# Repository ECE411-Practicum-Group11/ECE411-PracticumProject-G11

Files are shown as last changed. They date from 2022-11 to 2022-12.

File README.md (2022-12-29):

Fall 2022 ECE 411 Practicum Project 

<ins>Group 11 Team Members/Project Authors</ins> 
* Cesar Ordaz-Coronel
* Charles Nasser
* Anthony Bruno

# NERD BOX - A Handheld Video Game Console
<p align="center">
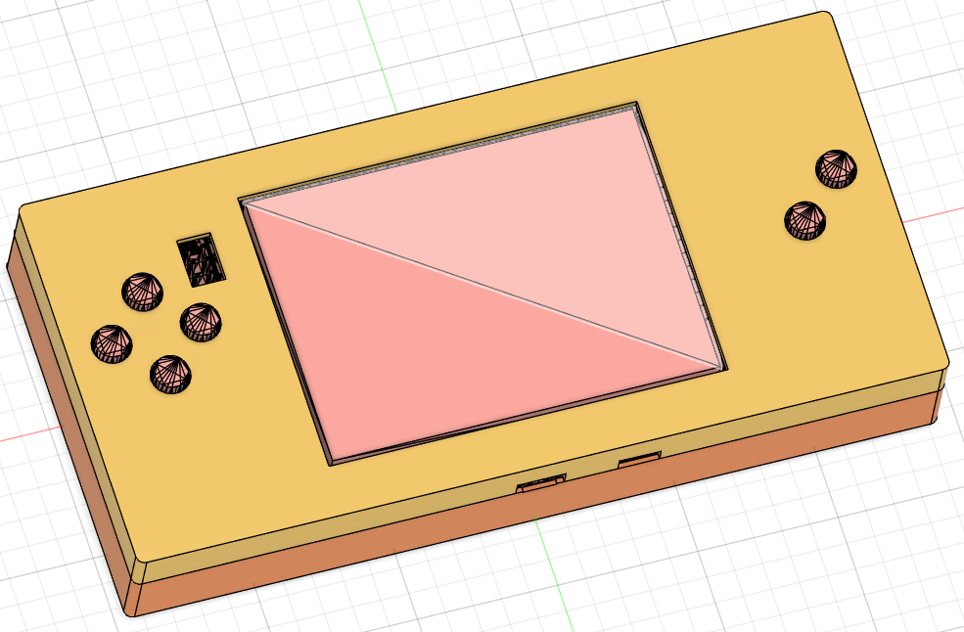
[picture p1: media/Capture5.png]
  
</p>
  
## Description:
This practicum project is for the development of a **Handheld Video Game Console**. This gaming device has buttons for users to interact with the device electronics and view game graphics/animations on the console's display. This device was designed for beginner-electronics users who want to code their own games (also build/modify/customize their own portable game console). The handheld game console is a portabe device with a simple interface for users.

<p align="center">
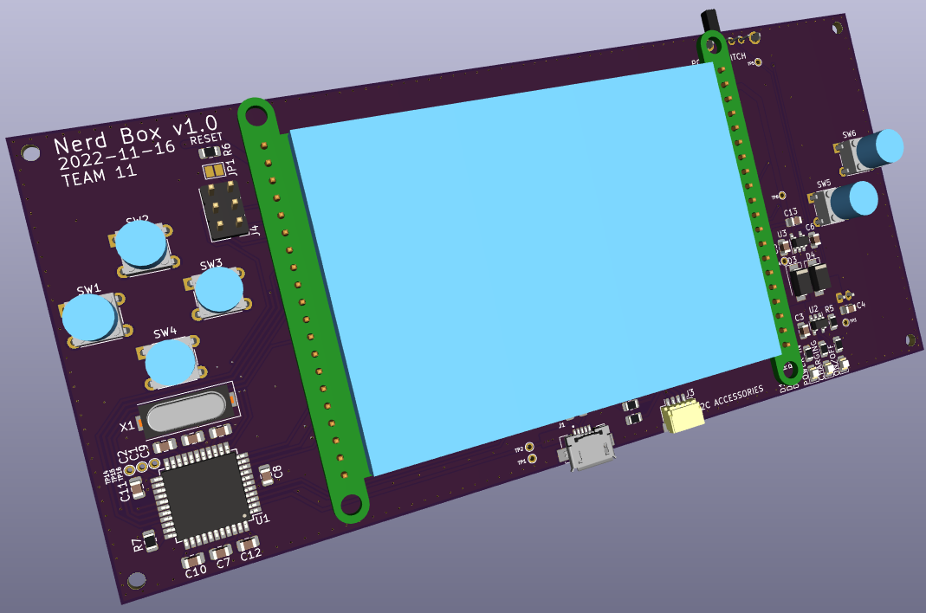
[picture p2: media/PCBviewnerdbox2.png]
  
</p>

This handheld game console was designed with a simple user interface and at a affortable cost. The device contains 4 direction/navigation buttons, 2 action buttons, power switch, and a [QWIIC I2C](https://www.sparkfun.com/qwiic) connector for adding accessory sensors and devices such as an [accelerometer](https://www.sparkfun.com/products/17589) for motion control with the Handheld Video Game Console. The system uses a 3.7V 2000mah LiPo battery that is rechargable through the USB connection. The USB connection serves to not only charge the LiPo battery but also for user to upload their own coded games. This device uses the Arduino IDE (Processing language) to code games and upload/interact with the system electronics hardware. The gaming device has a 3D printed enclosure that can be modified for customized enclosure designs.

## Overview of Repository Folders/Files/Sections

* 411documents - contains all documentation for the this project over the course of 10 weeks. This folder contains Level 1 and Level 0 functional decomposition block diagrams for the device, Bill of Materials, Proposed project schedule (Ghantt Chart), Test plans, project ideas, the Product Design Specification (PDS), device electrical schematics, device PCB layout, and 3D printed CAD files.

* code - This folder contains any code that was generated to run the device, test the device, and debug the device during development. The software in this folder includes test programs, UI code for user, prototype code, and device video game code examples.

* hardware/console-hardware - This folder contains all electrical schematics, PCB layout, components, CAD project, and mechanical CAD files. This is the main folder for DIY building, fabrication, modifications, or reworking this prjoect.

* media - this folder contains all media related to this project. This includes test videos, debugging videos, test images and protoype images, demonstration videos, photos, etc.

* LICENSE file - The current license of this practicum project is CREATIVE COMMONS ZERO V1.0 UNIVERSAL. This is an Open-Source License and this project is dedicated to the public domain. This project can be copied, modified, distributed, and performance of work (including commercial purposes) without asking for permission. For more information on CC0 1.0 Universal - Public Domain Dedication, please follow this link: https://creativecommons.org/publicdomain/zero/1.0/

* README.md file - A markdown file (this file) that explains a majority of the files and folders of this practicum project. 

* Team Information - A markdown file that contains information about the team members of this practicum project.

## System Architecture - Block Diagrams
For more system architecture details, go to the [411documents](https://github.com/ECE411-Practicum-Group11/ECE411-PracticumProject-G11/tree/main/411documents) folder in this repsitory and view the [G11_L1blockDiagram](https://github.com/ECE411-Practicum-Group11/ECE411-PracticumProject-G11/blob/main/411documents/G11_L1_blockDiagram.png)

<p align="center">
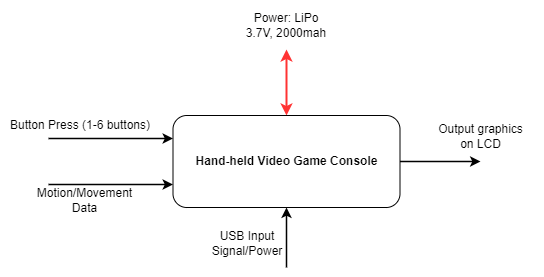
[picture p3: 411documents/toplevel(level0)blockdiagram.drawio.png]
  
</p>

## [Demonstration & Operations Video Link](https://www.youtube.com/playlist?list=PLfQtabAE1AbKebFBLS851gg_HdHH0sS15)

## License
The current license of this practicum project is CREATIVE COMMONS ZERO V1.0 UNIVERSAL. This is an Open-Source License and this project is dedicated to the public domain. This project can be copied, modified, distributed, and performance of work (including commercial purposes) without asking for permission. For more information on CC0 1.0 Universal - Public Domain Dedication, please follow this link: https://creativecommons.org/publicdomain/zero/1.0/

## How to Download Project & Tools to Use
1) Go to the project [Repository](https://github.com/ECE411-Practicum-Group11/ECE411-PracticumProject-G11)

2) Use one of the following options

### Option 1: Download ZIP
1) Click the GREEN "<>Code" dropdown.

2) Click on "Download ZIP".

3) After the download is complete, unzip the folder using [7zip](https://www.7-zip.org/), [PeaZip](https://peazip.github.io/), [WinZip](https://www.winzip.com/en/), or any other ZIP application.

### Option 2: Git Clone
If you know how to use Git/GitHub, you can clone the project repository
1) Click the GREEN "<>Code" dropdown.

2) Copy the https git link.

3) Open git bash on your current machine and move to the directly on your local machine where you would like to clone the project repository to.

4) type the following commands.

```
git clone [the http git link you copied, you can use SHIFT + INSERT for this]
```
Now you have a local repository for this project.

You can now access all files and documents of this project

## Tools For this Project
There are a few software tools that you will need in order to build, modify, or view the files in this project.

For the PCB design schematic, PCB layout, and any other items related to the electronics board, you can use any electronics CAD design and automation software. We highly recommend using [KiCAD EDA](https://www.kicad.org/) for this project, a free, open-source electronics CAD EDA.

For the 3D Printed enclosure the project includes STL files and an AutoDesk Fusion 360 Archive file. We recommend you use [Autodesk Fusion360 CAD](https://www.autodesk.com/products/fusion-360/personal) for the 3D printed enclosure, which is free for personal use.

For software development of the device and coding your own games, we recommend you use [Arduino IDE](https://www.arduino.cc/en/software). We also recommend reading the [tutorial for the 2.8" TFT LCD](https://learn.adafruit.com/adafruit-2-8-and-3-2-color-tft-touchscreen-breakout-v2/overview). We also recommend researching some of the libraries used in the original device program for more optimization (i.e [FloppyDerp_with_UI.ino](https://github.com/ECE411-Practicum-Group11/ECE411-PracticumProject-G11/tree/main/code/FloppyDerp_with_UI))

__IMPORTANT NOTE:__ If you plan to use Arduino IDE to upload your own programs and create your own code, you MUST burn the arduino IDE Bootloader to the ATmega32U4 Microcontroller in the project. We HIGHLY recommend you use an Arduino as an ISP for burning the bootloader to the IC. You can follow a tutorial on how to set this up and the burning process at [Arduino as ISP and Arduino Bootloaders](https://docs.arduino.cc/built-in-examples/arduino-isp/ArduinoISP).

__IMPORTANT NOTE:__ If you plan to use Arduino IDE to create code and upload to the Nerd Box, PLEASE set the "Board" under "Tools" dropdown to "Arduino Leonardo"!

## POWERING THE DEVICE!
The Nerd Box has two ways to power the device:
1) Power using LiPo Battery:
The Nerd Box can be powered using a LiPo battery with a JST connector on the back of the PCB. We recommend using a 3.7V, 2000mAh battery. [This one from Adafruit](https://www.adafruit.com/product/2011) is the best since it fits in the chassis and supplies around 40 hours of power to the Nerd Box.

2) Power over USB:
The Nerd Box can also be powered directly over the USB connection. When the Nerd Box's USB is connected, if there is a LiPo battery attached then the LiPo battery will be charged up. THIS IS HOW YOU CHARGE THE LIPO BATTERY IN THE DEVICE. Again the USB serves as a way of charging the LiPo battery and programming/uploading games to the device. The Nerd Box can be powered over the USB without the LiPo battery as well.

## Assembly, Fabrication, Tests Tips & Notes

* We recommend using [Oshpark](https://oshpark.com/) to have your own PCBs fabricated and using [Digi-Key](https://www.digikey.com/) for components.
* If you have a 3D printer or printer service with fine detail/quality, you can modify the 3D enclosure with labels. Otherwise, you can use [decals](https://www.youtube.com/watch?v=YWCaCXiLDwo&t=260s&ab_channel=Tim%27sProjects) on the 3D Prints.
* The recommended screw size and type is a M2.2, self-tapping flat head screw that is roughly 16mm to 19mm in length. Here are some recommendations from McMaster-Carr: [Link 1](https://www.mcmaster.com/catalog/128/3273), [Link 2](https://www.mcmaster.com/catalog/128/3273), [Link 3](https://www.mcmaster.com/screws/tapping-wood-and-drywall-screws/18-8-stainless-steel-phillips-flat-head-screws-for-sheet-metal/screw-size~m2-2/tip-type~pointed/)
* If you are planning to assemble the PCB yourself, we recommend that you solder a subcircuit first and then test with a bench power supply, then test with the LiPo battery. This ensures that everything will operate as expected. The order we recommend from the design schematics are: 3.3V Linear Regulator, LiPo Charger, USB Input Programming & Power, ATmega32U4 + ICSP, the rest of the components. Solder the LCD LAST! Also the board contains different test points. Reference the schematic on what each one does and utilize them in your testing!
* DO NOT USE A HEAT GUN OR PCB OVEN on the PCB with the LCD soldered down to the PCB! THIS WILL DAMAGE IT!
* Consideration: If you plan to have your board fabricated & fitted/assembled by another service, we recommend you add sodler bridges between subcircuits of the device and then add 0Ohm resistors to bridge the subcircuits together. This makes testing each subcircuit easier and able to use an assembly service.
* The 3D Prints for the enclosure don't have any labels for the buttons but you are free to modify the prints with labels. You can also just add decals onto the 3D prints. Go to YouTube or read any tutorials online on how to do this.

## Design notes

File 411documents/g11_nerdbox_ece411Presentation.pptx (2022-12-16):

## Nerd Box

Group 11
Charles Nasser, Cesar Ordaz-Coronel, Anthony Bruno

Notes: Intro slide
Have KiCAD with schematic, board, GitHub with Code section, BOM, Test Results Document,

## Background

The issue addressed:
- Portable Gaming + Open Source Hardware + Game Creation = One Solution
- Values of a Solution: Educational, Creativity, Enjoyment
Today’s Solutions
- High-end solutions = $$$ for individual, Discontinued, moves quickly
- Low-end solutions = Discontinued, sold out, Outdated, other

ArduBoy - Too small form factor

Steam Deck Retail: $400 starting

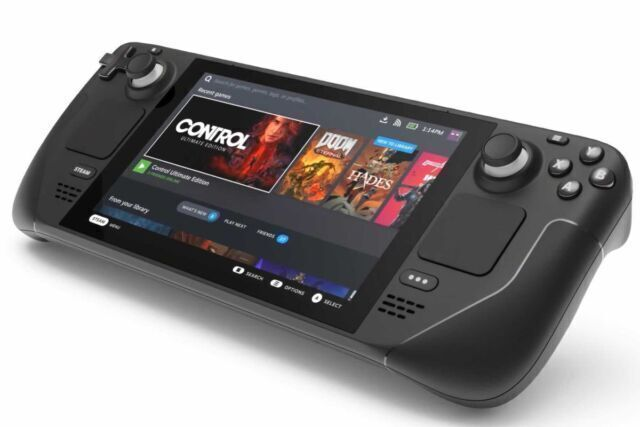
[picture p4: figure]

Meggy Jr RGB - Outdated HW

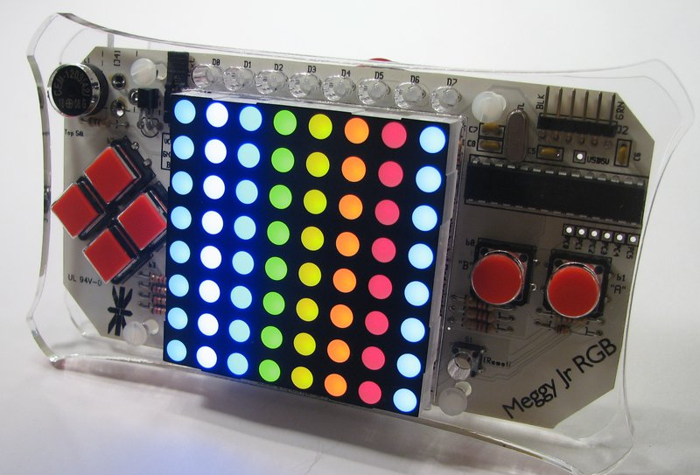
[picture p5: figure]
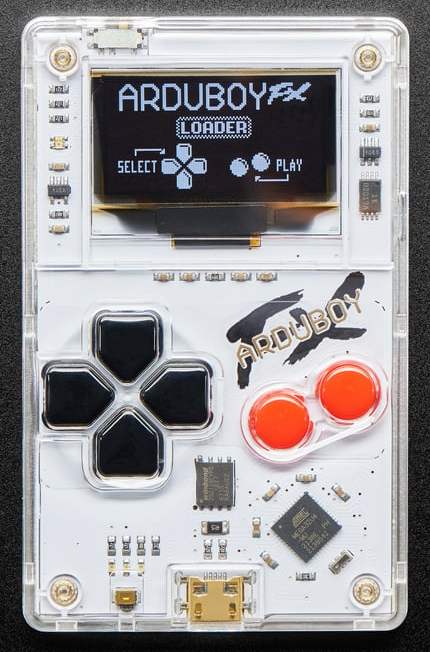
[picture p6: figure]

## Our Approach

Concept of Operations:
- User Input: device buttons, QWIIC (I2C) sensors
- Microcontroller: translates inputs to programmed outputs
- MVP Device Output: Display game animations/graphics
- Device programmed using Arduino IDE or Scratch programming
- USB for charging the battery
Objective: Deliver an open source hardware handheld, programmable gaming console to the video game console market that enables game development/creation and game hardware modification.

## Requirements (Approach continued….)

MUSTS:
- Be Handheld, Portable
- Battery Powered
- User Interface (UI)
- Display Response to inputs
- Menu/Navigation
- Programmable for games

MAYS:
- Memory device for storage of user settings, more memory-heavy games
- Battery Level LED indicators
- Use another monitor to display games on larger displays

SHOULDS:
- Non-button/switch input (motion, CV, etc.)
- 3D Printed Enclosure
- Other non-display outputs (sound, rumble)
- Battery charging

## Design Overview - L0

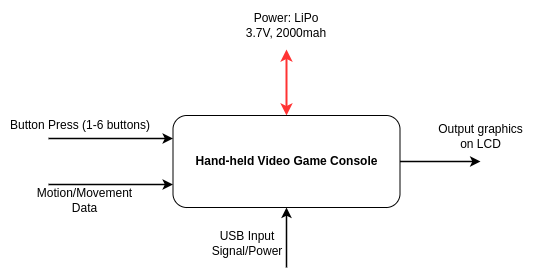
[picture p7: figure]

## Design Overview Continued…. L1

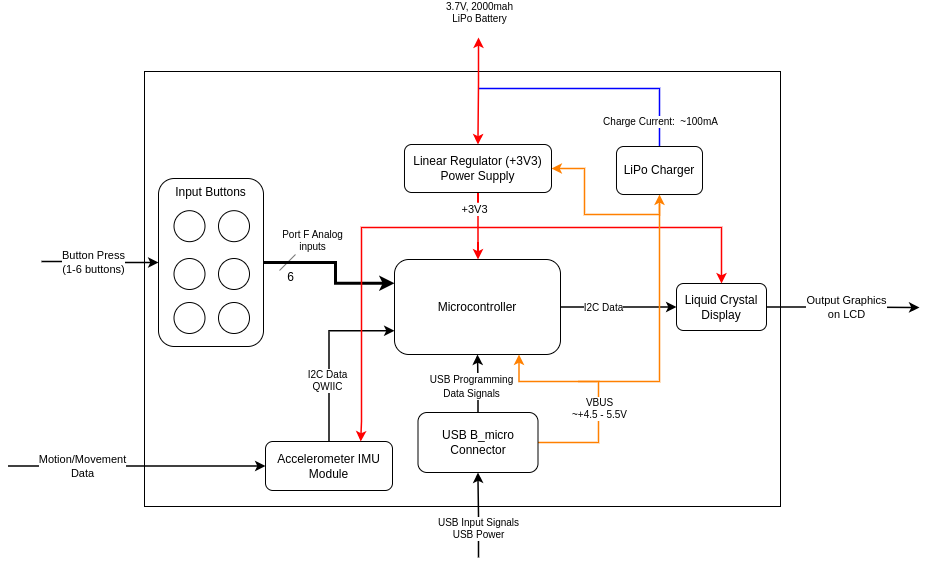
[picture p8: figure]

## Implementation

- Look at Design Schematics (https://github.com/ECE411-Practicum-Group11/ECE411-PracticumProject-G11/blob/main/411documents/console-hardware.pdf)
- Look at Design Board
- Look at Code (https://github.com/ECE411-Practicum-Group11/ECE411-PracticumProject-G11/tree/main/code)
- Tools: Arduino IDE, Fusion 360, kiCAD
- Look at BOM - Bill of Materials (https://docs.google.com/spreadsheets/d/1_oyUwwm-8SEYxP21QnwM3eA1EwvT7GKVv85xH6BpHFg/edit#gid=0)

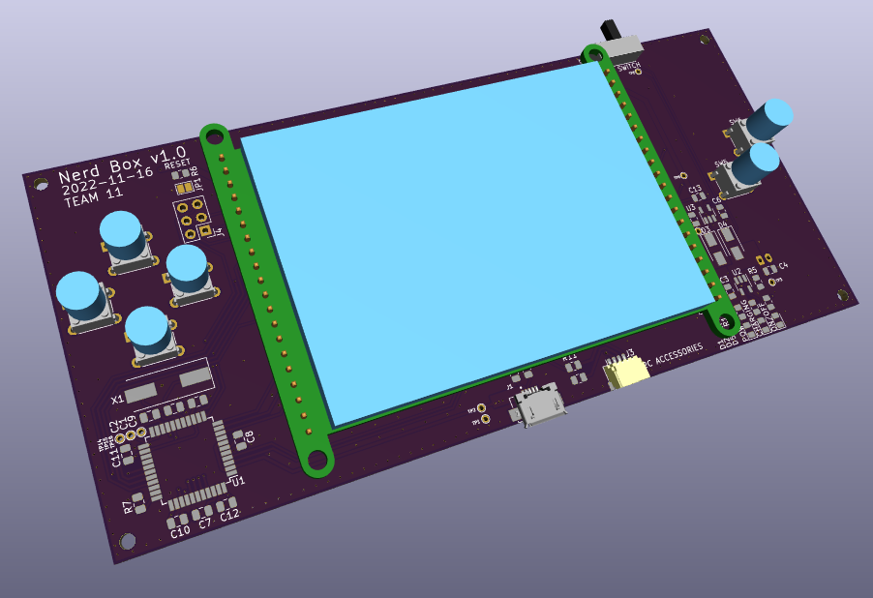
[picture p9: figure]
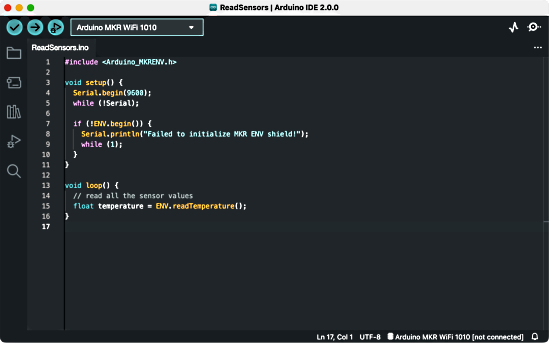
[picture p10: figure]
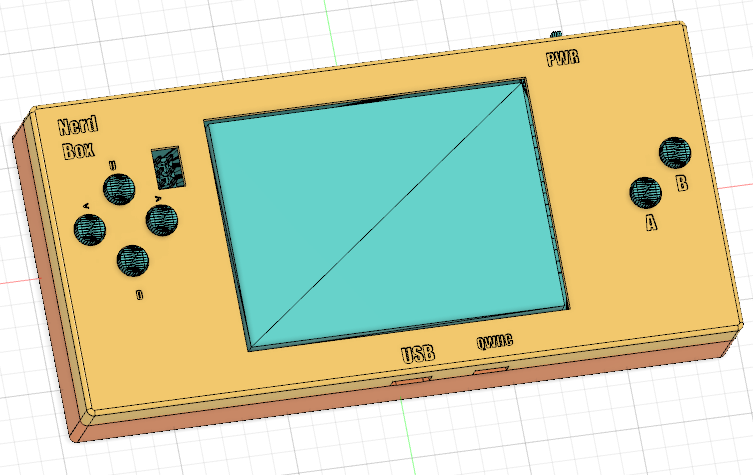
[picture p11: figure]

## IP License & Existing Work

License Chosen: Creative Commons Zero V1.0 Universal (https://creativecommons.org/publicdomain/zero/1.0/)
Other IP used:
- Based on Arduino Leonardo, Lilypad, Andrew Greenberg’s Example schematic (ATmega32U4 µC interface) - For Hardware
- Adafruit library documentation - For code
- Based on example game (https://www.toptal.com/game/ultimate-guide-to-processing-simple-game) coded in processing - Example code reference

## Testing

- In Design/Pre-test setup
  - Placement of Test Points (TP), ~ 16 TP
  - Code simple test software (Serial monitor printing, button presses, etc.)
- Assembly Testing
  - Solder [section] + Run with either Bench supply or Battery + measure TPs OR software testing
  - Section Order:
    - device power supply, LiPo charger, Microcontroller, USB, Display/buttons
  - Take video of tests
- Running the Test Plans → Show in the GDrive (https://drive.google.com/drive/u/0/folders/13O50pw37mKjkBTSg6qUxUUeUvg1ZXIF3)

## Results (for the PROJECT)

What Worked for us
- The output of the regulator showed +3V3
- Device display showing programmed graphics
- Device PASSED written test plans

What didn’t Work well for us
- Bootloader failure → switched to +5V from +3V3
- Display wasn’t functioning properly → Solder/close some pads on the 2.8” TFT display board to use SPI mode
- Problem accessing pins in software → Fixed pin naming in Arduino IDE

## Results (for the TEAM)

What worked for us
- Group communication messaging system (Discord)
- Regular scheduled meetings that fits with our schedules
- Checking each other’s work

What didn’t work so well for us
- Group of 3 (4 is better)
- Working on deliverable assignments day-before due date
- Extra meetings, difficult to schedule

## Contributions

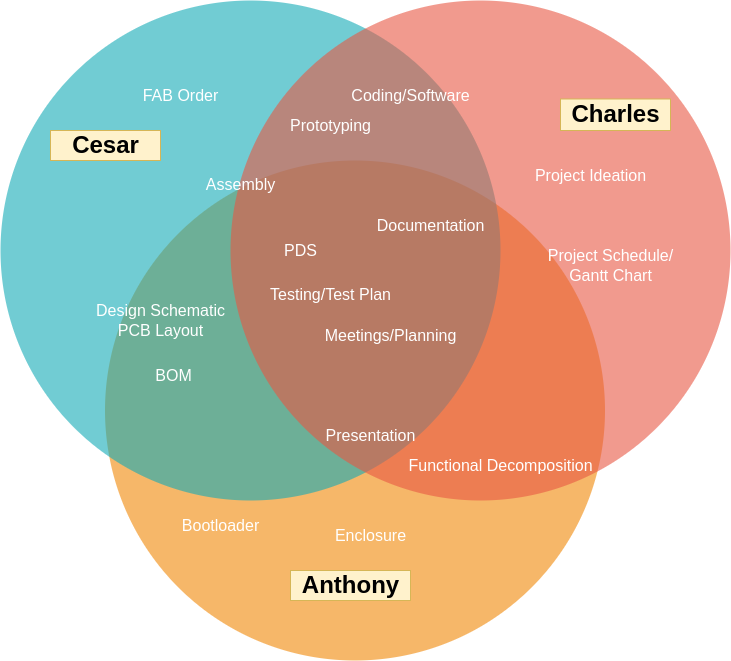
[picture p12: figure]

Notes: Use a venn diagram with each of our names and contributions

## Lessons Learned

- Communication in a project with a short development time is CRITICAL
- Help check each other’s work to verify
- Prototype early, Prototype with better parts
Time Machine - done differently……
- Add more memory w/ a different microcontroller
- Add more output features such as sound
- Add a battery indicator to the LCD
- Easier interface for users to add their code

## Alright….. Let’s Demo Demo Video if necessary

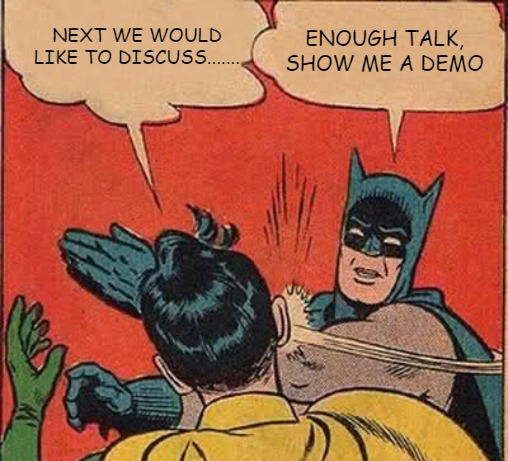
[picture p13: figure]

## Let’s look at the Collaboration site Link Here (https://github.com/ECE411-Practicum-Group11/ECE411-PracticumProject-G11)

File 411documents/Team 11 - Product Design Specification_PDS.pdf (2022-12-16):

# Practicum PDS - Project Design Specifications

Team 11: Anthony Bruno, Charles Nasser, Cesar Ordaz-Coronel

## Executive Summary (Concepts of Operations):

Our device is a handheld video game console. This device displays interactive games where the user interacts with the device (and the game) through a button interface. Users of our device are beginners in electronics who want to code their own games. Users interact with the device through a button system where they can make selections and navigate through the menu. User inputs are output to the display (and possibly a speaker). We have noticed that although there are existing devices, these devices are either discontinued, outdated, sold-out, expensive, or aren’t designed for user-created games. We want the freedom to design our own games that can be run on an open source hardware platform at an affordable cost.

## Brief Market Analysis:

- Intended Customers:
Our device is intended to be an open-source handheld game platform for electronics beginners who want to design/program their own games and play them on a portable device. Ideally, this device allows users to code their own games into it. So our users are those who enjoy open-source hardware and playing/creating handheld games.
- Competition/Differentiation:
The competition in this area is somewhat competitive. There are very high-end systems, such as the Nintendo Switch or Steam Deck, but also low-end systems that are open-source hardware, such as the ArduBoy or Evil Mad Scientist Meggy jr. RGB. However, high-end systems are very expensive to own and don’t offer the ability for users to create their own games (or at least not without a difficult process). Many of the low-end systems today are cheaper but are either sold-out, discontinued, or outdated. Some of them are open-source hardware but creating your own games is not intuitive to the casual observer.
- Estimated Selling Price: ~$65 after mass manufacturing

## Requirements:

Must:
- Be a handheld device that is portable.
- Be battery powered (swappable batteries).
- Have a user interface for the user to interact with the device

- Have the device display respond to a user’s action or input to the device.
- Have a menu for the user to navigate through and make selections.
- Be programmable → The user should be able to upload their own games to the device.

Should:
- Have non-button user input (motion control, computer vision, etc.)
- Have a 3D Printed enclosure to hold the device electronics and act as a handheld form factor for the device.
- Have non-LCD output such as controller rumble or a speaker for sound.
- Have battery charging

May:
- Be used on PC using the Arduino IDE Serial Monitor for display
- Have memory for saving user custom device settings or status of game.
- Have Battery level indicator LEDs.

## System Architecture (L1 Block Diagram):

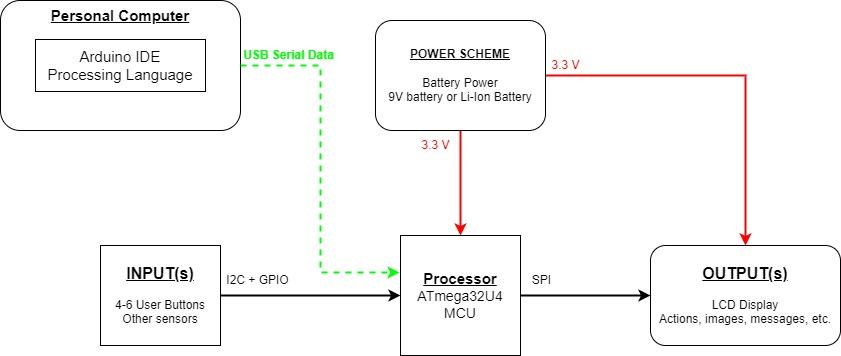
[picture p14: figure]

## Design Specifications:

- Sensor(s)(input): Buttons and motion controls (6-axis IMU)
- Processor: Arduino → ATmega32U4 (Microchip)
- Actuator(output): LCD and haptics (vibration or sound)
- Power Scheme: Battery Powered (9V battery, Li-Ion, LiPo, etc.)
- Mechanical Designs: 3D Printed enclosure
- Firmware/Bootloader:
- Processing (Arduino C++/C)
- Arduino IDE

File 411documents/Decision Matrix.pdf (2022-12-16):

# Practicum Decision Matrix and AHP

Team 11: Anthony, Charles, Cesar

## Question and Criteria

Our group was deciding on which battery technology to use for our handheld video game console. The three options were AA batteries, a 9V battery, and a LiPo battery.
We based this decision on the cost to manufacture, charge capacity, size, whether or not the battery was rechargeable, how easy they are to replace, and the nominal voltage.
We compared manufacture cost by finding rough estimates for the price of each battery when purchased in bulk.
For the charge capacity, we estimated how long the system would last with each battery relative to one another.
We ranked battery size by how much space they would take up, and ranked the thinner LiPo battery higher.
We gave AA batteries and 9V batteries a score of 2 for rechargeability since they are not usually rechargeable, but some can be found, while the LiPo scored 5.
The replacement score was based on how easy and convenient it would be for the user to replace the battery. AA and 9V batteries scored highly, since they are common and cheap, while the LiPo is much more expensive.
The nominal voltage rating was based on how easy it is to power a 3.3V system using the battery technology. AA batteries scored low, since at least 3 of them are needed in series to achieve this, and the 9V battery scored relatively low, since a large voltage drop is needed, which is inefficient when using a linear regulator.

## Decision Matrix

With the decision matrix, we found that the LiPo battery was the best option

AA Batteries (x3) | 9 V | Li-po
Manufacture Cost | 4 | 3 | 4 | 2
Charge Capacity | 4 | 4 | 3 | 4
Size (Small) | 3 | 3 | 3 | 5
Rechargeability | 3 | 2 | 2 | 5
Replacement (Access) | 2 | 5 | 5 | 1
Nominal Voltage | 2 | 2 | 3 | 5
SCORE | | 57 | 59 | 66

## AHP

The AHP method showed that the 9V battery is slightly better than the LiPo battery. This seems to be due to the high importance we gave to manufacturing cost, since the LiPo battery is much more expensive than the alternatives. Despite this, we are still inclined to choose the LiPo battery, which means that cost is less important to us than our weights show.

AHP Analysis | Weights | AA Batteries (x3) | 9V Battery | LiPo Battery
Manufacture Cost | 0.37 | 0.37 | 0.57 | 0.06
Charge Capacity | 0.25 | 0.36 | 0.21 | 0.43
Size (Small) | 0.22 | 0.13 | 0.25 | 0.63
Rechargeability | 0.08 | 0.22 | 0.22 | 0.56
Replacement (Access) | 0.04 | 0.45 | 0.45 | 0.09
Nominal Voltage | 0.04 | 0.20 | 0.30 | 0.50
SCORE | | 0.30 | 0.37 | 0.34

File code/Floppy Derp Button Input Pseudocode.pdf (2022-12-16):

# Pseudocode

Game Selection
1) Floppy Derp
2) Hungover Dude
3) {Insert your game here}

Set game select variable = 1
Button down -> increase var by 1, move cursor over selected game position
- If var = 1, button down does nothing
Button up -> decrease var by 1, move cursor over selected game position
- If var = 3, button up does nothing
“A” Button -> Play selected game (Run game function)

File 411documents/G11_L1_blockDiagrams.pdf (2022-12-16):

# Hand-held Video Game Console: Level 1

Team: G11
Team members: Anthony, Cesar, Charles

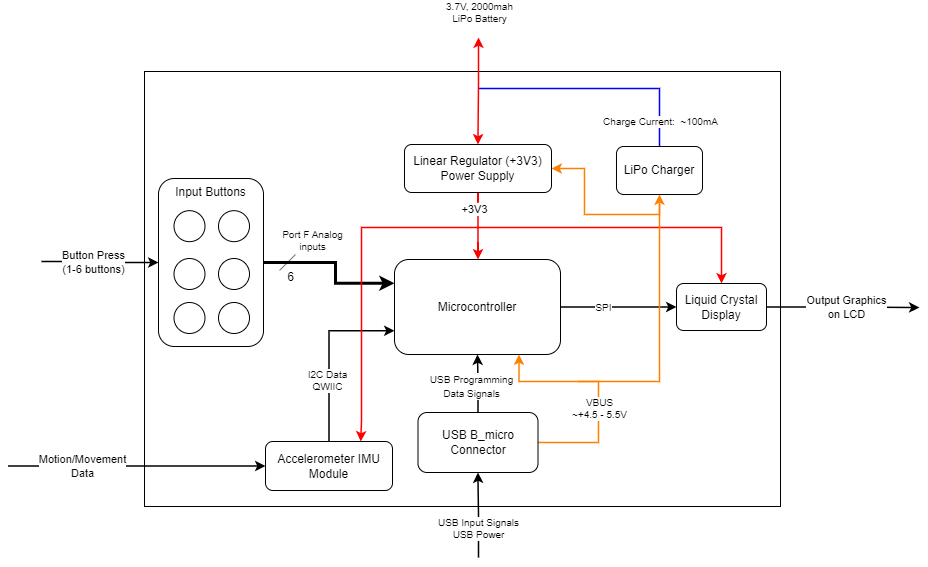
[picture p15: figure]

Microcontroller: Level 1

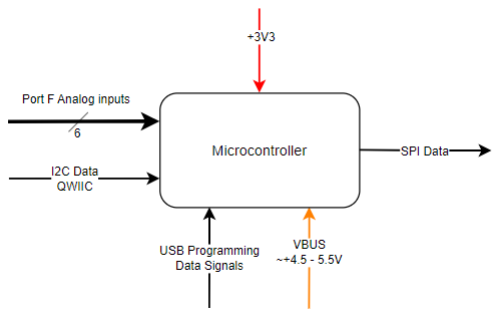
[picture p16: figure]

Module | Microcontroller (ATmega32u4)
Inputs | Port F Analog inputs: 6 analog inputs (pullups) to microcontroller’s ADC I2C Data (QWIIC): 6 DoF IMU data in I2C communication protocol from accelerometer/IMU module. QWIIC is Sparkfun’s I2C interface connection system for prototyping. +3V3: +3.3V DC power for Microcontroller USB Programming Data Signals: USB D+/D- programming signals to program the microcontroller behavior. VBUS (+4.5 - 5.5V): Supply from USB for programming, supplying the microcontroller
Outputs | SPI Data: SPI communication protocol data for graphics and animation on the Liquid Crystal Display module.
Functionality | Microcontroller block is the small computer that converts inputs from buttons and accelerometer module into output game graphics and animations on the LCD screen. It is the processor of the system.

Input Buttons: Level 1

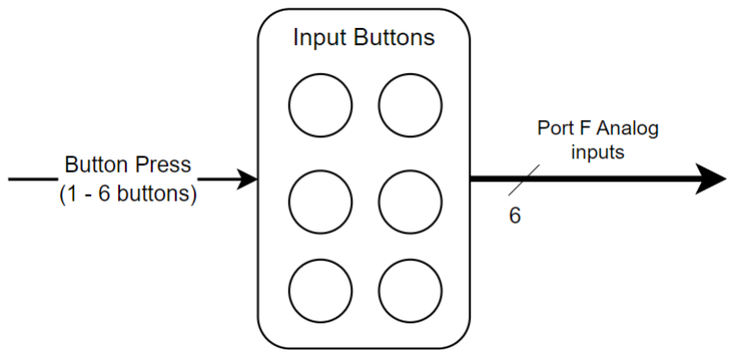
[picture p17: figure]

Module | Input Buttons
Inputs | Button Press (1-6 buttons): 6 tactile (pullup) buttons pressed by the user. User presses 1 of the 6 buttons.
Outputs | Port F Analog inputs (to microcontroller): 6 analog inputs (pullups) to microcontroller’s ADC
Functionality | User presses 1 of the 6 tactile buttons which acts as analog input to the microcontroller’s ADC on Port F. These buttons are pulled up (high) and the active input is low.

Accelerometer IMU Module: Level 1

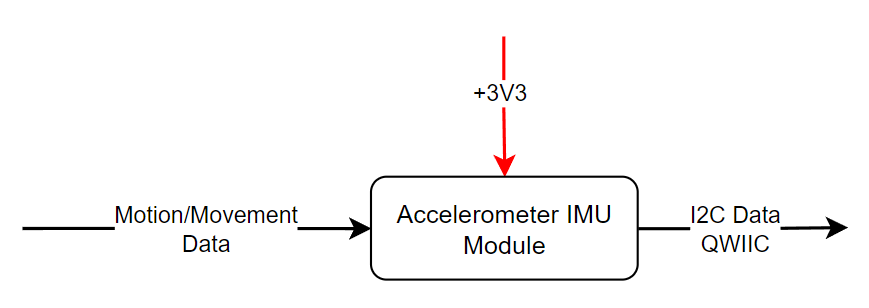
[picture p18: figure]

Module | Accelerometer IMU Module
Inputs | Motion/Movement Data: Data that is generated by physically moving and orienting the Accelerometer module in 3D space. Captured by the Accelerometer module. +3V3: +3.3V DC power for the Accelerometer IMU module
Outputs | I2C Data (QWIIC): 6 DoF IMU motion data in I2C communication protocol (acceleration, orientation, etc.). QWIIC is Sparkfun’s I2C interface connection system for prototyping.
Functionality | Moving the accelerometer IMU module around in 3D space will capture motion data (acceleration, orientation, etc.) and output this data to the microcontroller using I2C communication protocol.

LiPo Charger: Level 1

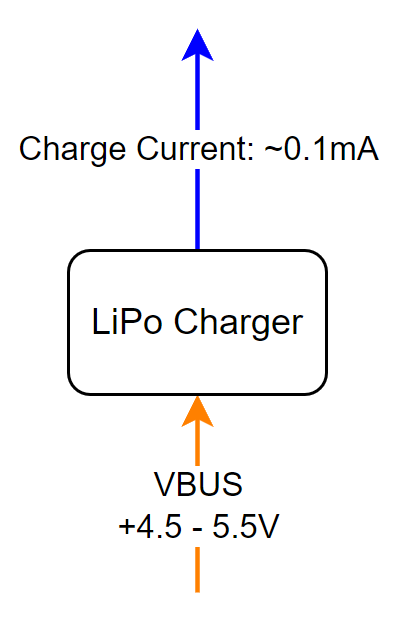
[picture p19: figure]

Module | LiPo Charger (MCP73831)
Inputs | VBUS (+4.5 - 5.5V): Supply from USB VBUS supplying the LiPo charger and charging the LiPo battery.
Outputs | Fast charge current: ~0.1mA 1000V I REG = wℎere R PROG = 10kΩ R PROG
Functionality | Charges the LiPo battery in the system. The fast charge current is around 0.1mA.

Liquid Crystal Display: Level 1

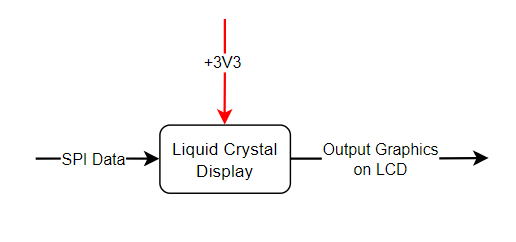
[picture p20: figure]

Module | Liquid Crystal Display (2.8” TFT LCD (https://www.adafruit.com/product/2090) from adafruit)
Inputs | +3V3: +3.3V DC power for LCD module SPI Data: SPI communication protocol data from the microcontroller to the Liquid Crystal Display module.
Outputs | Output Graphics on LCD: The game console’s graphics and animations displayed to the user on the LCD’s pixels.
Functionality | This LCD displays the video game console’s graphics and animations. The I2C data is sent to the LCD and the LCD controls the pixels on the LCD based on this data sent.

USB B_micro Connector: Level 1

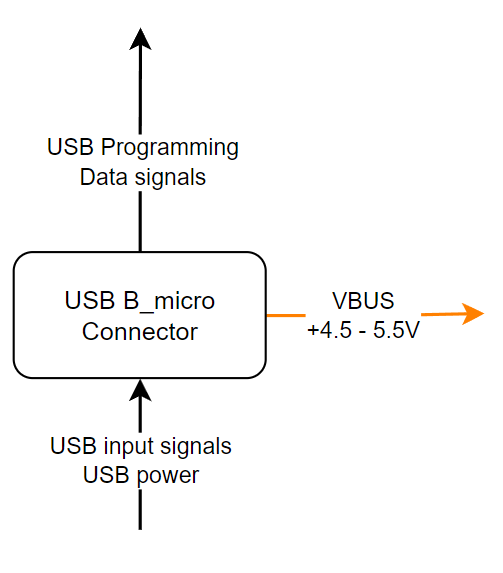
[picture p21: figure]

Module | USB B_micro connector
Inputs | USB input signals/USB Power: USB communication protocol and power supply. USB input signals and power come from a Desktop or laptop running Arduino IDE with USB driver.
Outputs | USB Programming Data Signals: USB D+/D- programming signals to program the microcontroller behavior. VBUS (+4.5 - 5.5V): Supply from USB, supplying the microcontroller, charging the LiPo Battery, source for Linear regulator
Functionality | This is the connector for the USB communication protocol. The connector takes USB D+/D- to program the microcontroller. The connector also fans out the VBUS supply to the microcontroller, LiPo charger, and Linear regulator

Linear Regulator (+3V3) Power Supply: Level 1

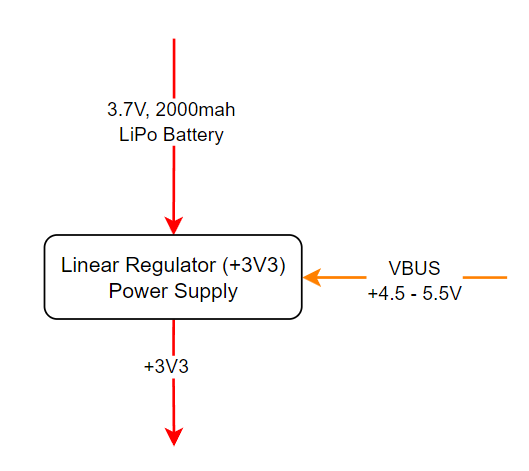
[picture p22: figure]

Module | Linear Regulator (+3V3) Power Supply
Inputs | VBUS (+4.5 - 5.5V): Supply from USB, supplying the microcontroller, charging the LiPo Battery, source for Linear regulator (+3V3) 3.7V, 2000mah LiPo Battery: Lithium Polymer battery source for the hand-held game console. Charged using LiPo Charger component
Outputs | +3V3: +3.3V DC power for LCD module, Microcontroller, accelerometer IMU module.
Functionality | This is the power supply for the hand-held game console. It regulates the power by delivering a steady +3.3V DC supply to the microcontroller, LCD module, and accelerometer IMU module.

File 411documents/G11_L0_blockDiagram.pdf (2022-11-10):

# Hand-hand Video Game Console: Level 0

Team: G11
Team members: Anthony, Cesar, Charles

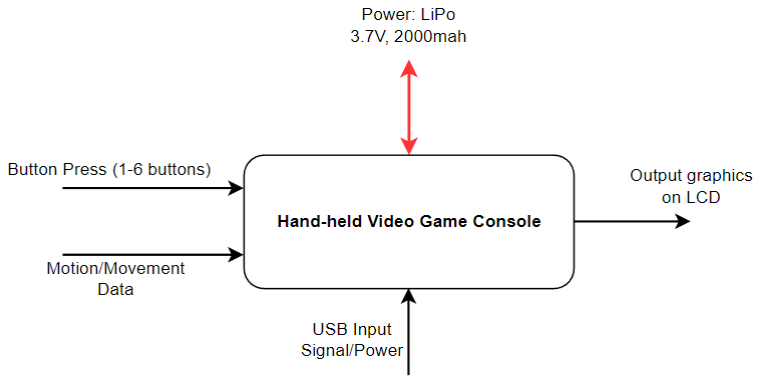
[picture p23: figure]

Module | Hand-held Video Game Console
Inputs | 6 Input Buttons: pullups, tactile. Press 1 of the 6 buttons to interact with the game console and control the output on the display (menu navigation, game actions/control, etc.) Motion/Movement Data: 6 DoF IMU (accelerometer & Gyroscope). Module translation motion/orientation to IMU data read by the game console and interpreted as motion control input for games. USB Input Signal/Power: USB B Micro, for programming device, USB power to charge LiPo battery. Power: 3.7V 2000mah LiPo battery, w/ charging from USB power
Outputs | Output Graphics on LCD: Game console produces an output signal to the Liquid Crystal Display module to show game content, video, and images.
Functionality | Displays video game graphics/animations (actions, messages, images, etc.) based on input from user button presses and accelerometer motion data. Powered by a 3.7V 2000mah LiPo battery that can be charged through the device using a USB input. The device is programmed using the USB input.

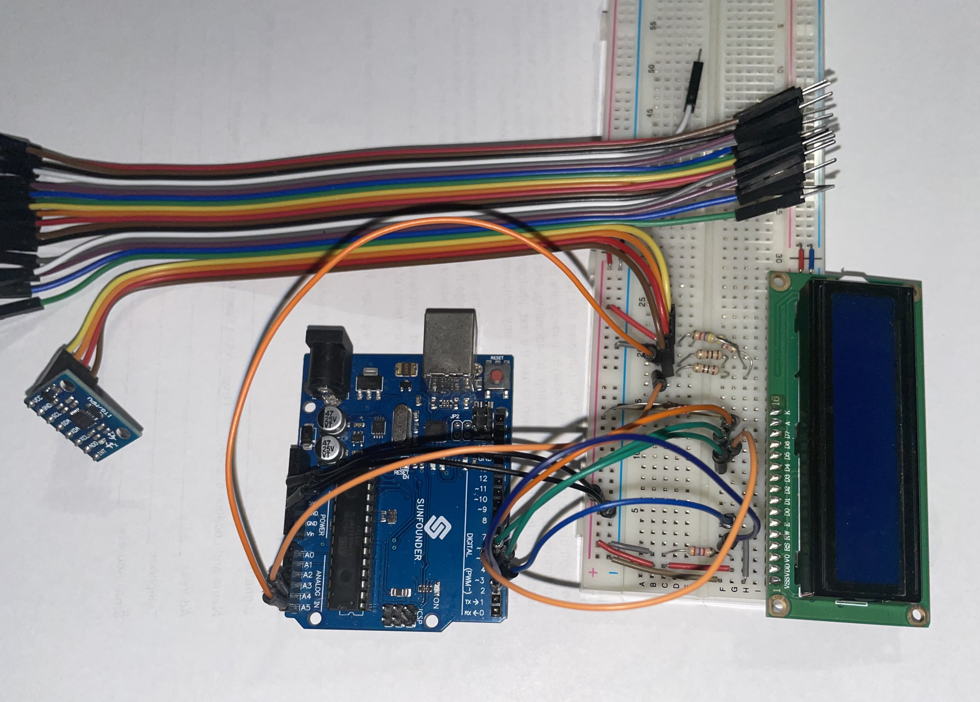
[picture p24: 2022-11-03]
media/Team 11 - Breadboard Prototype.jpg

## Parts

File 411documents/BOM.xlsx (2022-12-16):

Bill Of Materials for: Team 11
Last modified: 12/06/2022 |  |  | TOTAL DEVICE COST |  | $81.10
PCB version: 1.0
BOM revision: 3 |  | P/NP | = Place/Not Place (components marked NP are not stuffed on the board)
Qty | References | P/DNP | MFR | MPN | Description | Dist | DPN | price per unit | Total cost | Availability | Ordered | Received
2 | C1, C2, | P | Stackpole | CML0805C0G300JT50V | 30 pF 0806 Ceramic capacitor | Digi-Key | 738-CML0805C0G300JT50VCT-ND | $0.10 | $0.20 | TRUE | TRUE | TRUE
4 | C3, C4, C5, C13 | P | Samsung | CL21A475KAQNNNG | 4.7 uF 0806 Ceramic capacitor | Digi-Key | 1276-6462-1-ND | $0.10 | $0.40 | TRUE | TRUE | TRUE
1 | C6, | P | Samsung | CL21B471KBANFNC | 470 nF 0806 Ceramic capacitor | Digi-Key | 1276-2515-1-ND | $0.10 | $0.10 | TRUE | TRUE | TRUE
5 | C7, C9, C10, C11, C12, | P | Samsung | CL21B104KACNNNC | 100 nF 0806 Ceramic capacitor | Digi-Key | 1276-1099-1-ND | $0.10 | $0.50 | TRUE | TRUE | TRUE
1 | C8, | P | Samsung | CL21B105KAFNNNE | 1 uF 0806 Ceramic capacitor | Digi-Key | 1276-1066-1-ND | $0.10 | $0.10 | TRUE | TRUE | TRUE
3 | D1, D2, D5, | P | Rohm | SML-210MTT86 | Green 0806 LED | Digi-Key | 511-1287-1-ND | $0.37 | $1.11 | TRUE | TRUE | TRUE
2 | D3, D4, | P | Vishay | B340A-M3/61T | Schottky diode | Digi-Key | B340A-M3/61TGICT-ND | $0.43 | $0.86 | TRUE | TRUE | TRUE
1 | J1, | P | Wurth | 629105136821 | USB Micro Type B connector | Digi-Key | 732-3155-1-ND | $1.29 | $1.29 | TRUE | TRUE | TRUE
1 | J2, | P | JST | S2B-PH-K-S(LF)(SN) | LiPo battery connector | Digi-Key | 455-1719-ND | $0.17 | $0.17 | TRUE | TRUE | TRUE
1 | J3, | P |  | 10147606-00004LF | 4 pin JST connector | Digi-Key | 609-6302-1-ND | $0.67 | $0.67 | TRUE | TRUE | TRUE
1 | J4, | P | Harwin | M20-9980346 | 2x3 2.54mm Pin header | Digi-Key | 952-2121-ND | $0.30 | $0.30 | TRUE | TRUE | TRUE
1 | J5, | P | Adafruit |  | 2.8" TFT LCD with Cap Touch Breakout Board | Adafruit | 2090 | $39.95 | $39.95 | TRUE | TRUE | TRUE
2 | R1, R2, | P | Yageo | RC0805FR-1322RL | 22 Ohm 0806 resistor | Digi-Key | 13-RC0805FR-1322RLCT-ND | $0.10 | $0.20 | TRUE | TRUE | TRUE
5 | R3, R4, R8, R9, R12, | P | Yageo | RC0805JR-074K7L | 4.7k 0806 resistor | Digi-Key | 311-4.7KARCT-ND | $0.10 | $0.50 | TRUE | TRUE | TRUE
3 | R5, R6, R7, | P | Yageo | RC0805JR-0710KL | 10k 0806 resistor | Digi-Key | 311-10KARCT-ND | $0.10 | $0.30 | TRUE | TRUE | TRUE
2 | R10, R11, | P | Yageo | RC0805JR-070RL | 0 ohm 0806 resistor | Digi-Key | 311-0.0ARCT-ND | $0.10 | $0.20 | TRUE | TRUE | TRUE
6 | SW1, SW2, SW3, SW4, SW5, SW6, | P | Omron | B3F-1052 | Tactile Switch | Digi-Key | SW405-ND | $0.38 | $2.28 | TRUE | TRUE | TRUE
1 | SW7, | P | E-Switch | EG1213 | SPDT slide switch | Digi-Key | EG1906-ND | $0.76 | $0.76 | TRUE | TRUE | TRUE
1 | U1, | P | Microchip | ATMEGA32U4-AU | ATMEGA32U4 microcontroller | Digi-Key | ATMEGA32U4-AU-ND | $5.68 | $5.68 | TRUE | TRUE | TRUE
1 | U2, | P | Microchip | MCP73831T-2DCI/OT | Single cell, Li-Ion/Li-Po charge management controller, 4.20V, Tri-State Status Output, in SOT23-5 package | Digi-Key | MCP73831T-2DCI/OTCT-ND | $0.76 | $0.76 | TRUE | TRUE | TRUE
1 | U3, | P | Microchip | MIC5219-3.3YM5-TR | 500mA low dropout linear regulator, fixed 3.3V output, SOT-23-5 | Digi-Key | 576-1281-1-ND | $1.20 | $1.20 | TRUE | TRUE | TRUE
1 | X1, | P | Wurth | 830011263 | 16 MHz crystal | Digi-Key | 1923-830011263CT-ND | $0.35 | $0.35 | TRUE | TRUE | TRUE
6 | - | DNP | Omron | B32-2010 | Button cap | Digi-Key | SW1139-ND | $0.94 | $5.64 | TRUE | TRUE | TRUE
1 | - | DNP |  |  | Printed Circuit Board for Nerd Box design | - |  | $17.58 | $17.58 | TRUE | TRUE | TRUE
 |  |  |  |  |  |  |  |  | $0.00
 |  |  |  |  |  |  | TOTAL DEVICE COST |  | $81.10

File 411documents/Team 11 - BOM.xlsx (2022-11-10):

Bill Of Materials for: Team 11
Last modified: 11/10/2022
PCB version: 1.0
BOM revision: 1 |  | P/NP | = Place/Not Place (components marked NP are not stuffed on the board)
Qty | References | P/DNP | MFR | MPN | Description | Dist | DPN
2 | C1, C2, |  | Stackpole | CML0805C0G300JT50V | 30 pF 0806 Ceramic capacitor | Digi-Key | 738-CML0805C0G300JT50VCT-ND
3 | C3, C4, C5, |  | Samsung | CL21A475KAQNNNG | 4.7 uF 0806 Ceramic capacitor | Digi-Key | 1276-6462-1-ND
1 | C6, |  | Samsung | CL21B471KBANFNC | 470 nF 0806 Ceramic capacitor | Digi-Key | 1276-2515-1-ND
5 | C7, C9, C10, C11, C12, |  | Samsung | CL21B104KACNNNC | 100 nF 0806 Ceramic capacitor | Digi-Key | 1276-1099-1-ND
1 | C8, |  | Samsung | CL21B105KAFNNNE | 1 uF 0806 Ceramic capacitor | Digi-Key | 1276-1066-1-ND
3 | D1, D2, D5, |  | Rohm | SML-210MTT86 | Green 0806 LED | Digi-Key | 511-1287-1-ND
2 | D3, D4, |  | Vishay | B340A-M3/61T | Schottky diode | Digi-Key | B340A-M3/61TGICT-ND
1 | J1, |  | Molex | 476420001 | USB Micro Type B connector | Digi-Key | WM1398CT-ND
1 | J2, |  | JST | S2B-PH-K-S(LF)(SN) | LiPo battery connector | Digi-Key | 455-1719-ND
1 | J3, |  |  |  | 4 pin JST connector | Adafruit | 4208
1 | J4, |  | Harwin | M20-9980346 | 2x3 2.54mm Pin header | Digi-Key | 952-2121-ND
1 | J5, |  |  |  | Pin header and display module | Adafruit | 2090
2 | R1, R2, |  | Yageo | RC0805FR-1322RL | 22 Ohm 0806 resistor | Digi-Key | 13-RC0805FR-1322RLCT-ND
5 | R3, R4, R8, R9, R12, |  | Yageo | RC0805JR-074K7L | 4.7k 0806 resistor | Digi-Key | 311-4.7KARCT-ND
9 | R5, R6, R7, R13, R14, R15, R16, R17, R18, |  | Yageo | RC0805JR-0710KL | 10k 0806 resistor | Digi-Key | 311-10KARCT-ND
2 | R10, R11, |  | Yageo | RC0805JR-070RL | 0 ohm 0806 resistor | Digi-Key | 311-0.0ARCT-ND
6 | SW1, SW2, SW3, SW4, SW5, SW6, |  |  |  | Push buttons | Digi-Key | 1010
1 | SW7, |  | E-Switch | EG1213 | SPDT slide switch | Digi-Key | EG1906-ND
1 | U1, |  | Microchip | ATMEGA32U4-AU | ATMEGA32U4 microcontroller | Digi-Key | ATMEGA32U4-AU-ND
1 | U2, |  | Microchip | MCP73831T-2DCI/OT | Single cell, Li-Ion/Li-Po charge management controller, 4.20V, Tri-State Status Output, in SOT23-5 package | Digi-Key | MCP73831T-2DCI/OTCT-ND
1 | U3, |  | Microchip | MIC5219-3.3YM5-TR | 500mA low dropout linear regulator, fixed 3.3V output, SOT-23-5 | Digi-Key | 576-1281-1-ND
1 | X1, |  | Wurth | 830011263 | 16 MHz crystal | Digi-Key | 1923-830011263CT-ND

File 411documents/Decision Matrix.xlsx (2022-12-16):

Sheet: Decision Matrix
 |  | AA Batteries (x3) | 9 V | Li-po
Manufacture Cost | 4 | 3 | 4 | 2
Charge Capacity | 4 | 4 | 3 | 4
Size (Small) | 3 | 2 | 3 | 5
Rechargeability | 3 | 2 | 2 | 5
Replacement (Access) | 2 | 5 | 5 | 1
Nominal Voltage | 2 | 2 | 3 | 5
SCORE |  | 54 | 59 | 66

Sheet: AHP
AHP - Weighting | Manufacture cost | Charge Capacity | Size(Small) | Rechargability | Replacement (Access) | Nominal Voltage | Mean | Weight
Manufacture Cost | 1 | 3 | 3 | 3 | 5 | 7 | 3.13 | 0.37
Charge Capacity | 0.3333333333 | 1 | 3 | 3 | 5 | 7 | 2.17 | 0.25
Size (Small) | 0.3333333333 | 0.3333333333 | 1 | 7 | 7 | 7 | 1.83 | 0.22
Rechargeability | 0.3333333333 | 0.3333333333 | 0.1428571429 | 1 | 3 | 3 | 0.72 | 0.08
Replacement (Access) | 0.2 | 0.2 | 0.1428571429 | 0.3333333333 | 1 | 1 | 0.35 | 0.04
Nominal Voltage | 0.1428571429 | 0.1428571429 | 0.1428571429 | 0.3333333333 | 1 | 1 | 0.31 | 0.04
AHP Analysis | Weights | AA Batteries (x3) | 9V Battery | LiPo Battery
Manufacture Cost | 0.37 | 0.37 | 0.57 | 0.06
Charge Capacity | 0.25 | 0.36 | 0.21 | 0.43
Size (Small) | 0.22 | 0.12 | 0.25 | 0.62
Rechargeability | 0.08 | 0.22 | 0.22 | 0.56
Replacement (Access) | 0.04 | 0.45 | 0.45 | 0.09
Nominal Voltage | 0.04 | 0.20 | 0.30 | 0.50
SCORE |  | 0.30 | 0.37 | 0.34

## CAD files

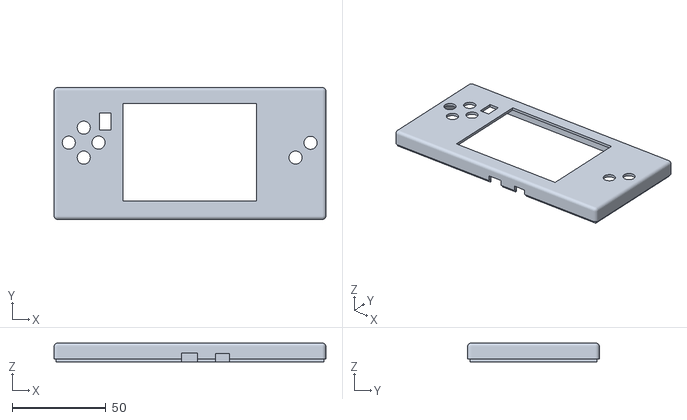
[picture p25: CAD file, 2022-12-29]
hardware/console-hardware/mechanicalCAD/nerdboxEnclosure3_top.stl
145.4 x 70.4 x 10.0

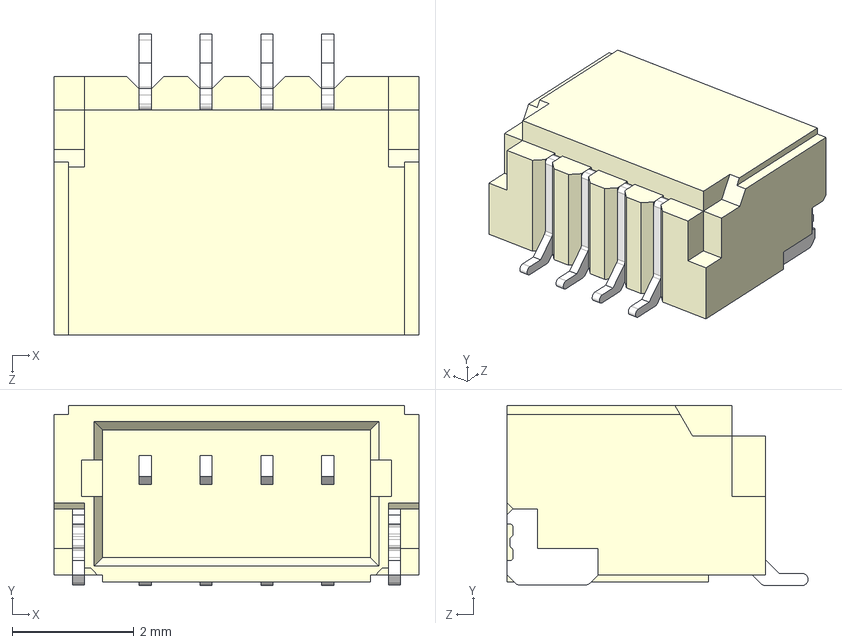
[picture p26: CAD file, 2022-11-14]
hardware/console-hardware/SM04B-SRSS-TB(LF)(SN)--3DModel-STEP-56544.STEP
6.00 x 2.96 x 4.95 mm

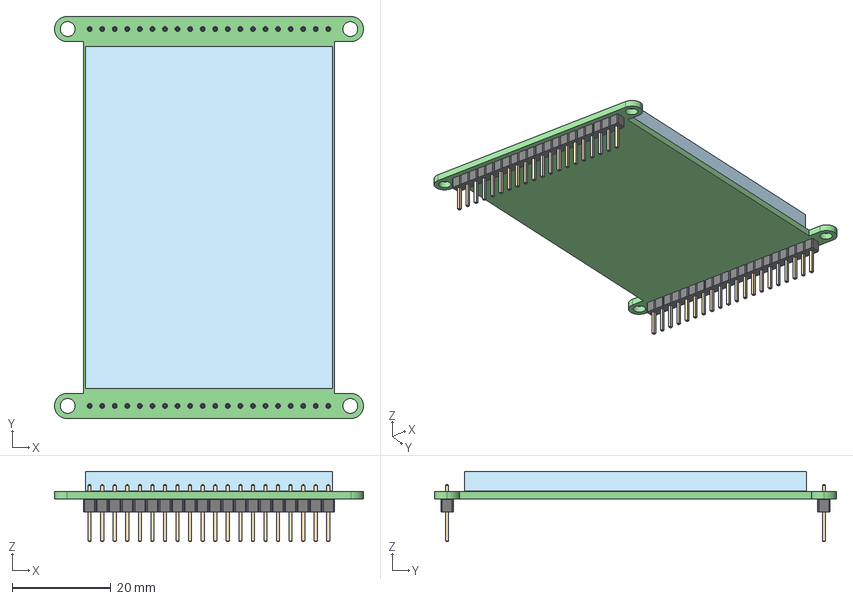
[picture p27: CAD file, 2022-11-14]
hardware/console-hardware/lcd_module.step
62.5 x 81.3 x 14.2 mm
_autosave-lcdboard PCB

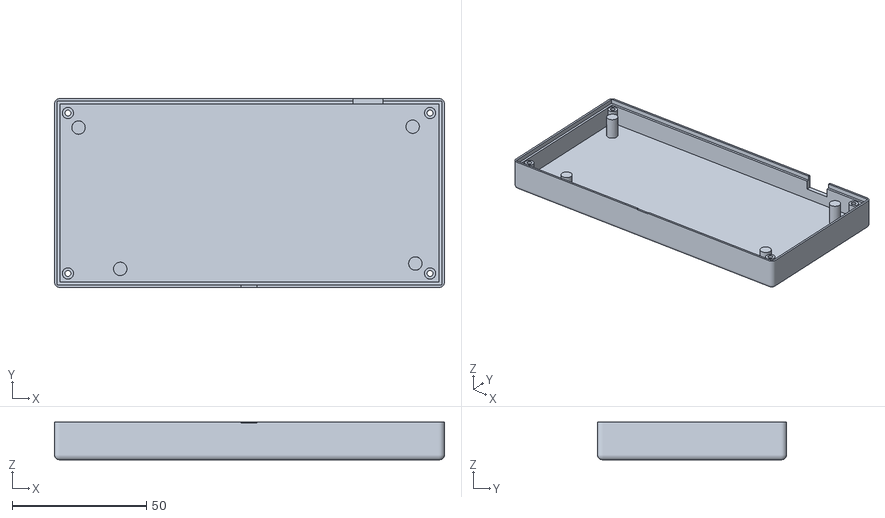
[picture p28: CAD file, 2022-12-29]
hardware/console-hardware/mechanicalCAD/nerdboxEnclosure3_bottom.stl
145.4 x 70.4 x 14.0

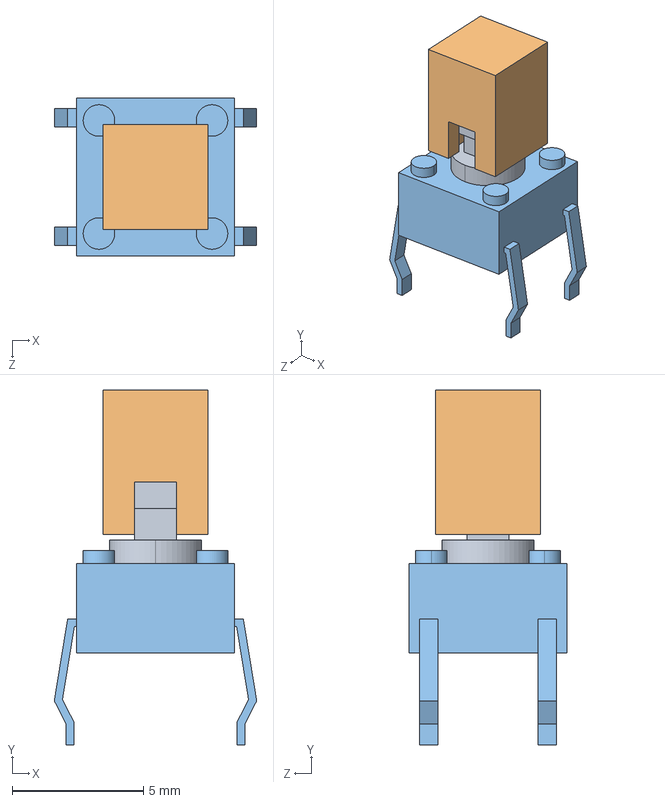
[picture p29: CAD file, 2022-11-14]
hardware/console-hardware/B3F_1052.step
7.70 x 13.5 x 6.00 mm
B3F_1052_BUTTON
B32_1000
B3F_1052_BASE

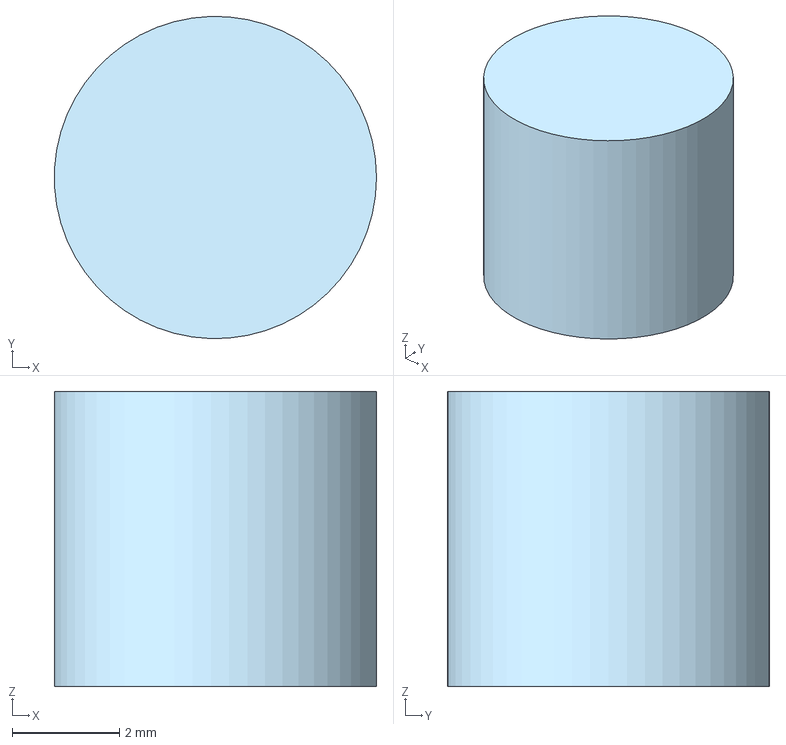
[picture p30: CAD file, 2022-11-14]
hardware/console-hardware/Button_Cap.step
6.00 x 6.00 x 5.50 mm

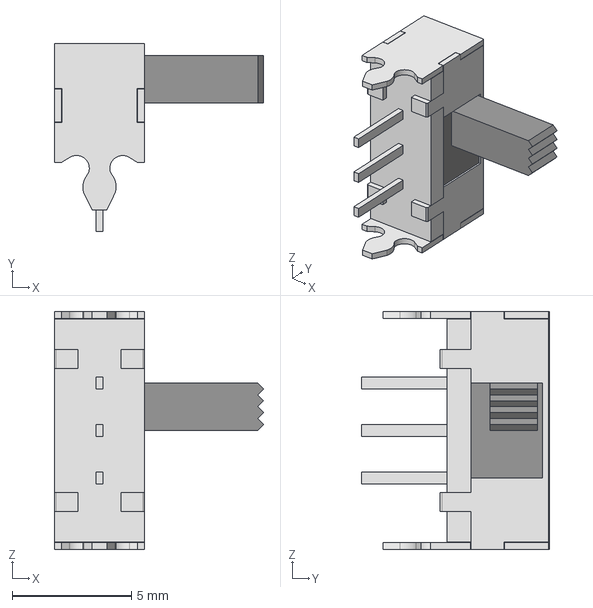
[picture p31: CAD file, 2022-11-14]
hardware/console-hardware/EG1213.step
8.80 x 7.90 x 10.00 mm

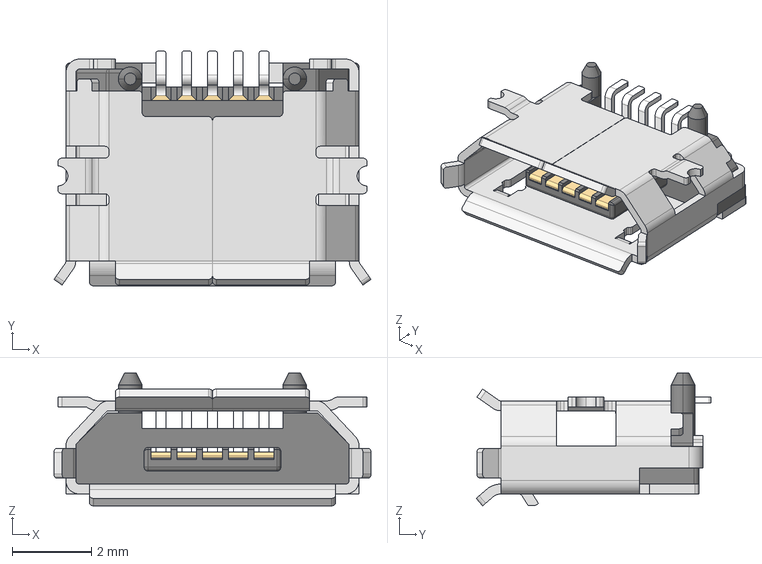
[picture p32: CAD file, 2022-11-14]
hardware/console-hardware/629105136821.step
8.00 x 5.92 x 3.35 mm

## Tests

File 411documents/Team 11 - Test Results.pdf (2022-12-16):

Test Author: Team 11
Test Case Name: | Battery Functionality Test | Test ID #: | BAT-FT-01
Description: | Test whether the li-po battery charges via the micro USB port without physical removal, and test whether it can power the system portably. | Type: | □ black box ☑ white box □ ________

Tester Information
| Name of Tester: | Cesar, Anthony | Date: | 2022-12-05
| HW/SW Version: | 1.0 | Time: | 14:47
| Setup: | Requires a fully assembled system. Disassemble the enclosure so that the battery is accessible.
STEP Action | | Expected Result | PASS FAIL | | N/A | Comments
1 | Measure initial battery voltage | Expected voltage between 3.2 and 4.2 V | Y | | | 3.98 V
2 | Plug 3.3+ V battery into system (With power switch off) | There should be no noticeable change | | | Y
3 | Turn on system power switch | The display and the “on/off” LED should turn on | Y | | | LED is dim
4 | Run hardware for 3 hours of runtime | If battery fully discharges, display and LED will turn off | Y | | | Ran for 10 minutes
5 | Measure battery voltage | Expected voltage will be lower than the initial voltage | Y | | | 3.97 V
6 | Plug in USB power cable to charge battery to full | The “power in”, and “charging” LEDs should turn on Expected voltage should be around 4.2 V | Y
7 | Repeat steps 1-6 | Results should be similar at each step | Y
| Overall test result: | | Pass

Test Author: Team 11
Test Case Name: | Hardware Test | Test ID #: | HW-FT-01
Description: | Test that both the hardware inputs / outputs function as expected. Also tests additional hardware components like the voltage regulator. | Type: | □ black box ☑white box □ ________

Tester Information
| Name of Tester: | Cesar, Anthony | Date: | 2022-12-05
| HW/SW Version: | 1.0 | Time: | 15:00
| Setup: | Requires a fully assembled system with enclosure disassembled, and the battery disconnected. Should include test software to verify the display and button functionality. The power switch should initially be turned off.
STEP | Action | Expected Result | PASS FAIL N/AComments
1 | Power the system with 5.0 V power supply, current limited to 150 mA into TP2, and GND into TP1. | Only the “power in” LED should turn on. | Y
2 | Turn on system power switch | The display and the “on/off” LED should turn on. Display Main Menu. | Y
3 | Measure voltage regulator TP6 | Should read 3.3 V (+3.3V DC) | Y | | | Measured 3.27 V
4 | Unplug power supply, and use USB power. | | | | Y
5 | Open Arduino IDE and upload the test software | The software should upload with no errors, and the display will read “Nerd Box v1.0 Test” | Y
6 | Open the serial monitor and press each button | Serial monitor and display show name of each button pressed sequentially. | Y
| Overall test result: | | Pass

Test Author: Team 11
Test Case Name: | Software Programmability Test | Test ID #: | SW-FT-01
Description: | Tests the user interface functionality, and the ability to upload custom game software to the device. | Type: | ☑ black box □ white box

Tester Information
| Name of Tester: | Cesar, Anthony | Date: | 2022-12-05
| HW/SW Version: | 1.0 | Time: | 15:20
| Setup: | Requires a fully assembled system powered via battery or USB power.
STEP Action | | Expected Result | PASS FAIL | | N/A | Comments
1 | Turn on system power switch. | The display and the “on/off” LED should turn on. Display Main Menu. Highlight Main Menu option 1: “Floppy Derp” | Y
2 | Press the D-direction button. | The display highlights Main Menu option 2: “Insert your game here!” | Y
3 | Press L-direction, R-direction, D-direction, and B buttons any number of times in random order. | No change after any key press. | Y
4 | Press the D-direction button. | Highlight Main Menu option 2: “Your Game Here” | Y
5 | Press A button. | The display reads “Plug in the Nerd Box and upload game code to select here! (Press B to return to Main Menu)” | Y
6 | Press B button. | Return to Main Menu. | Y
7 | Upload Floppy Derp game code. | The code should compile with no errors. Display Main Menu. | Y
8 | Press L-direction, R-direction, U-direction, and B buttons any number of times in random order. | No change after any key press. | Y
9 | Press A button. | Execute the Floppy Derp programmable software. | Y
| Overall test result: | | Pass

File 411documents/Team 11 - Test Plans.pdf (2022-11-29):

Test Author: Team 11
Test Case Name: | Baery Funconality Test | Test ID #: | BAT-FT-01
Descripon: | Test whether the li-po baery charges via the micro USB port without physical removal, and test whether it can power the system portably. | Type: | □ black box ☑ white box □ ________

Tester Informaon
| Name of Tester: | | Date:
| HW/SW Version: | 1.0 | Time:
| Setup: | Requires a fully assembled system. Disassemble the enclosure so that the baery is accessible.
STEP Acon | | Expected Result | PASS FAIL N/A Comments
1 | Measure inial baery voltage | Expected voltage between 3.2 and 4.2 V
2 | Plug 3.3+ V baery into system (With power switch off) | There should be no noceable change
3 | Turn on system power switch | The display and the “on/off” LED should turn on
4 | Run hardware for 3 hours of runme | The display and the “on/off” LED should turn off
5 | Measure baery voltage | Expected voltage will be lower than the inial voltage
6 | Plug in USB power cable to charge baery to full | The “power in”, and “charging” LEDs should turn on Expected voltage should be around 4.2 V
7 | Repeat steps 1-6 | Results should be similar at each step
| Overall test result:

Test Author: Team 11
Test Case Name: | Hardware Test | Test ID #: | HW-FT-01
Descripon: | Test that both the hardware inputs / outputs funcon as expected. Also tests addional hardware components like the voltage regulator. | Type: | □ black box ☑white box □ ________

Tester Informaon
| Name of Tester: | | Date:
| HW/SW Version: | 1.0 | Time:
| Setup: | Requires a fully assembled system with enclosure disassembled, and the baery disconnected. Should include test soware to verify the display and buon funconality. The power switch should inially be turned off.
STEP | Acon | Expected Result | PASS FAIL N/AComments
1 | Power the system with 5.0 V power supply, current limited to 50 mA into TP2, and GND into TP1. | Only the “power in” LED should turn on.
2 | Measure voltage regulator TP6 | Should read 3.3 V (+3.3V DC)
3 | Turn on system power switch | The display and the “on/off” LED should turn on. Display Main Menu.
4 | Unplug power supply, and use USB power.
5 | Open Arduino IDE and upload the test soware | The soware should upload with no errors, and the display will read “Nerd Box v1.0 Test”
6 | Open the serial monitor and press each buon | Serial monitor and display show name of each buon pressed sequenally.
| Overall test result:

Test Author: Team 11
Test Case Name: | Soware Programmability Test | Test ID #: | SW-FT-01
Descripon: | Tests the user interface funconality, and the ability to upload custom game soware to the device. | Type: | ☑ black box □ white box

Tester Informaon
| Name of Tester: | | Date:
| HW/SW Version: | 1.0 | Time:
| Setup: | Requires a fully assembled system powered via baery or USB power.
STEP Acon | | Expected Result | PASS FAIL N/A Comments
1 | Turn on system power switch. | The display and the “on/off” LED should turn on. Display Main Menu. Highlight Main Menu opon 1: “Floppy Derp”
2 | Press the D-direcon buon. | The display highlights Main Menu opon 2: “Insert your game here!”
3 | Press L-direcon, R-direcon, D-direcon, and B buons any number of mes in random order. | No change aer any key press.
4 | Press the U-direcon buon. | Highlight Main Menu opon 1: “Floppy Derp”
5 | Press A buon. | The display reads “Plug in the Nerd Box and upload game code to select here! (Press B to return to Main Menu)”
6 | Press B buon. | Return to Main Menu.
7 | Upload Floppy Derp game code. | The code should compile with no errors. Display Main Menu.
8 | Press L-direcon, R-direcon, U-direcon, and B buons any number of mes in random order. | No change aer any key press.
9 | Press A buon. | Execute the Floppy Derp programmable soware.
| Overall test result:

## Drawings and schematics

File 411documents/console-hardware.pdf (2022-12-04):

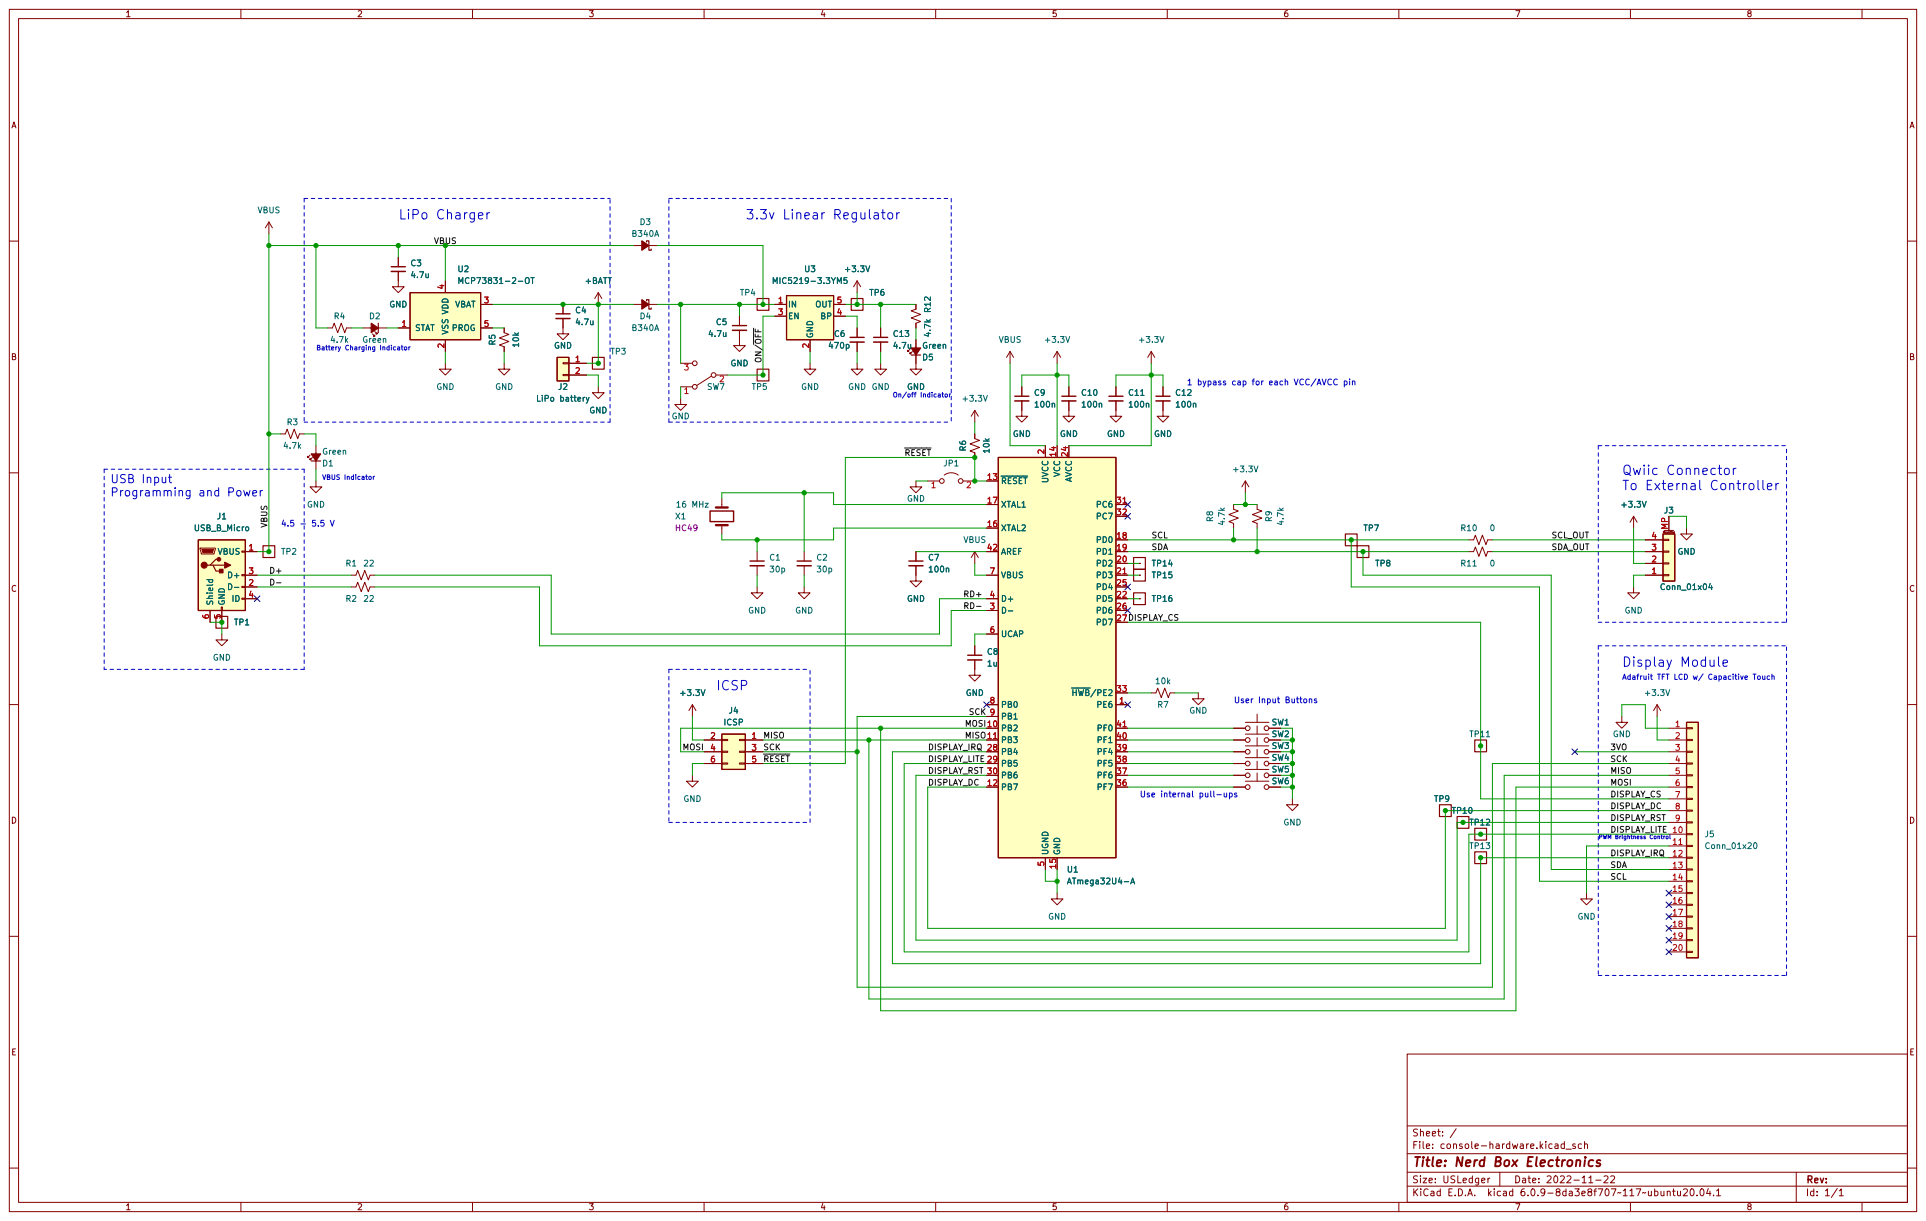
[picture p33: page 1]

On/off Indicator LiPo Charger 4.5 - 5.5 V

2 PD2 20 PD3 21 PD5 22 AVCC 24 PD4 25 PD6 26 PD7 27 PB4 28 PB5 29 D- 3 PB6 30 PC6 31 PC7 32 ~{HWB}/PE233 PF7 36 PF6 37 PF5 38 PF4 39 D+ 4 PF1 40 PF0 41 AREF 42 UGND

Qwiic Connector
To External Controller Adafruit TFT LCD w/ Capacitive Touch

10

Use internal pull-ups

PWM Brightness Control 11
DISPLAY_IRQ 12

13
14
15

File: console-hardware.kicad_sch Sheet: /
Id: 1/1 Title: Nerd Box Electronics

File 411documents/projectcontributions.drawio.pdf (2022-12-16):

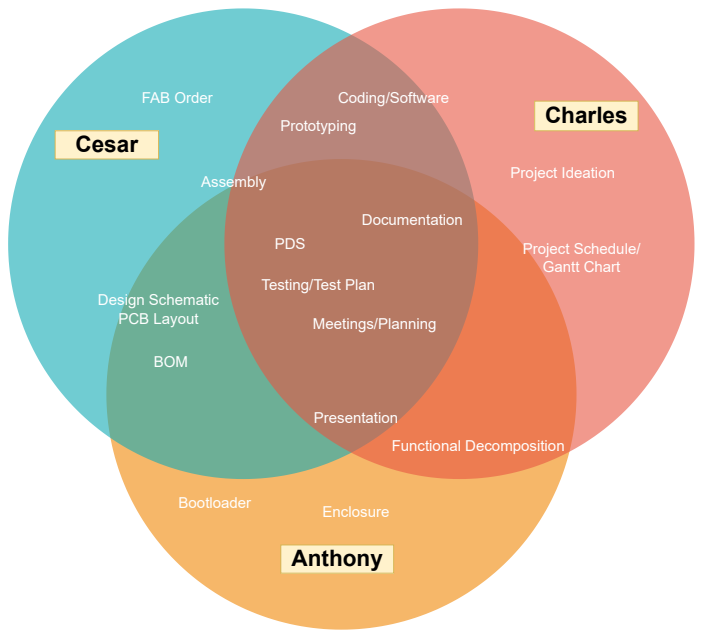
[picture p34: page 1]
Cesar; Charles; Anthony; Coding/Software; Bootloader; Design Schematic PCB Layout; Assembly; Enclosure; Project Ideation; Documentation; PDS; Functional Decomposition; Project Schedule/ Gantt Chart; FAB Order; Presentation; Prototyping; Meetings/Planning; BOM

Testing/Test Plan

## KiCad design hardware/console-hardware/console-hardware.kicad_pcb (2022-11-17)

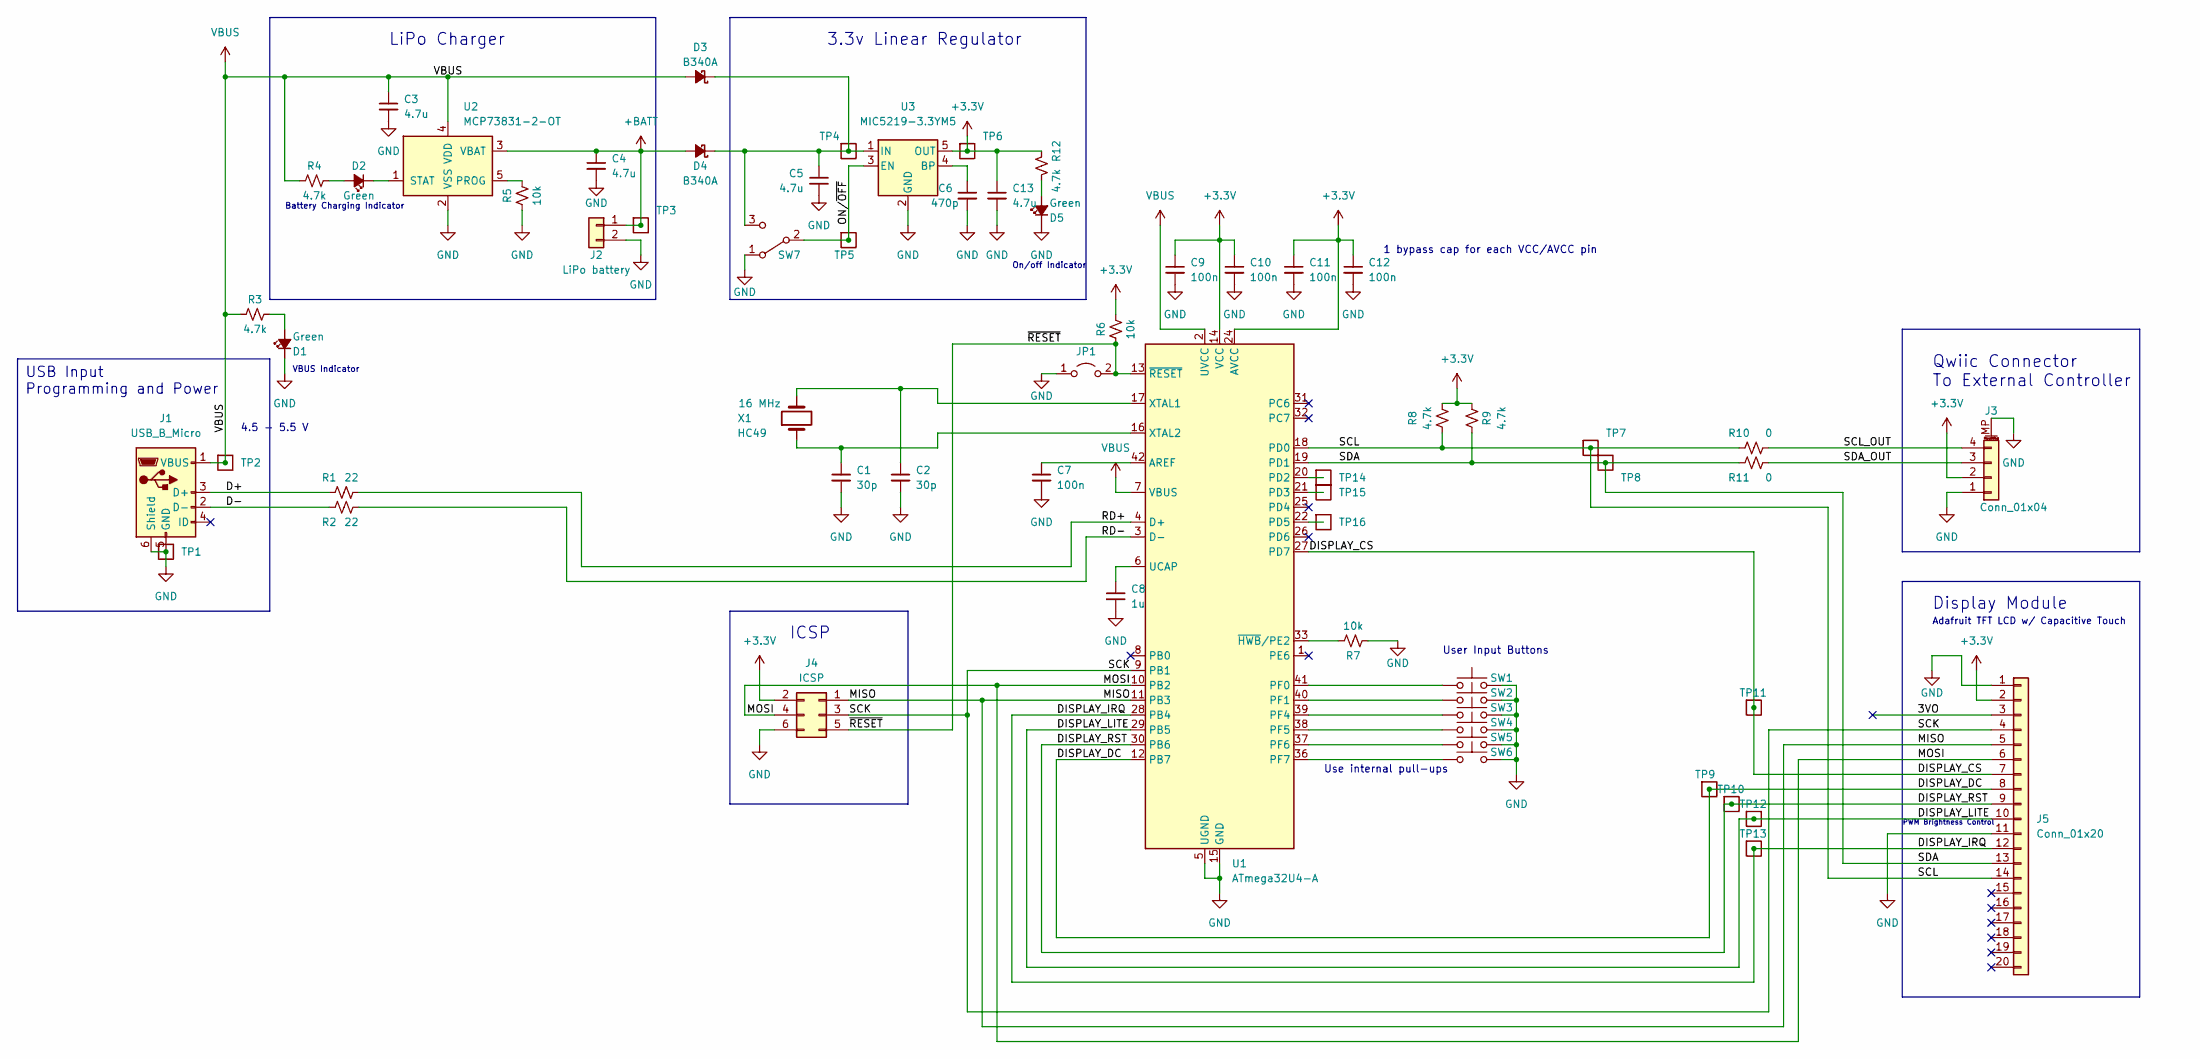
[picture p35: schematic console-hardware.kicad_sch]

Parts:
C1, C2: 30p; C_0805_2012Metric; MPN CML0805C0G300JT50V
C3, C4, C5, C13: 4.7u; C_0805_2012Metric; MPN CL21A475KAQNNNG
C6: 470p; C_0805_2012Metric; MPN CL21B471KBANFNC
C7, C9, C10, C11, C12: 100n; C_0805_2012Metric; MPN CL21B104KACNNNC
C8: 1u; C_0805_2012Metric; MPN CL21B105KAFNNNE
D1, D2, D5: Green; LED_0805_2012Metric; MPN SML-210MTT86
D3, D4: B340A; D_SMA; MPN B340A-M3/61T
J1: USB_B_Micro; WE_629105136821; MPN 629105136821
J2: LiPo battery; JST_PH_S2B-PH-K_1x02_P2.00mm_Horizontal; MPN S2B-PH-K-S(LF)(SN)
J3: Conn_01x04; JST_SH_SM04B-SRSS-TB_1x04-1MP_P1.00mm_Horizontal
J4: ICSP; PinHeader_2x03_P2.54mm_Vertical; MPN M20-9980346
J5: Conn_01x20; PinHeader_1x20_P2.54mm_Vertical
JP1: Jumper_2_Open; SolderJumper-2_P1.3mm_Open_Pad1.0x1.5mm
R1, R2: 22; R_0805_2012Metric; MPN RC0805FR-1322RL
R3, R4, R8, R9, R12: 4.7k; R_0805_2012Metric; MPN RC0805JR-074K7L
R5, R6, R7: 10k; R_0805_2012Metric; MPN RC0805JR-0710KL
R10, R11: 0; R_0805_2012Metric; MPN RC0805JR-070RL
SW1, SW2, SW3, SW4, SW5, SW6: SW_Push; SW_TH_Tactile_Omron_B3F-10xx; MPN B3F-1052
SW7: SW_SPDT; SW_EG1213; MPN EG1213
TP1, TP2, TP3, TP4, TP5, TP6, TP7, TP8, TP9, TP10, TP11, TP12, TP13, TP14, TP15, TP16: Test-Point; 1X01
U1: ATmega32U4-A; TQFP-44_10x10mm_P0.8mm; MPN ATMEGA32U4-AU
U2: MCP73831-2-OT; SOT-23-5; MPN MCP73831T-2DCI/OT
U3: MIC5219-3.3YM5; SOT-23-5; MPN MIC5219-3.3YM5-TR
X1: 16 MHz; Crystal_SMD_HC49-SD; MPN 830011263

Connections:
+3.3V: C9.1, C10.1, C11.1, C12.1, C13.1, J3.2, J4.2, J5.2, R6.2, R8.2, R9.2, R12.1, TP6.1, U1.14 (VCC), U1.24 (AVCC), U1.34 (VCC), U1.44 (AVCC), U3.5 (OUT)
+BATT: C4.1, D4.2 (A), J2.1, TP3.1, U2.3 (VBAT)
/3VO: J5.3
/D+: J1.3 (D+), R1.1
/D-: J1.2 (D-), R2.2
/DISPLAY_CS: J5.7, TP11.1, U1.27 (PD7)
/DISPLAY_DC: J5.8, TP9.1, U1.12 (PB7)
/DISPLAY_IRQ: J5.12, TP13.1, U1.28 (PB4)
/DISPLAY_LITE: J5.10, TP12.1, U1.29 (PB5)
/DISPLAY_RST: J5.9, TP10.1, U1.30 (PB6)
/MISO: J4.1, J5.5, U1.11 (PB3)
/MOSI: J4.4, J5.6, U1.10 (PB2)
/ON/~OFF: SW7.2 (B), TP5.1, U3.3 (EN)
/RD+: R1.2, U1.4 (D+)
/RD-: R2.1, U1.3 (D-)
/SCK: J4.3, J5.4, U1.9 (PB1)
/SCL: J5.14, R8.1, R10.2, TP7.1, U1.18 (PD0)
/SCL_OUT: J3.4, R10.1
/SDA: J5.13, R9.1, R11.1, TP8.1, U1.19 (PD1)
/SDA_OUT: J3.3, R11.2
/~RESET: J4.5, JP1.2 (B), R6.1, U1.13 (~RESET)
GND: C1.2, C2.2, C3.2, C4.2, C5.2, C6.2, C7.2, C8.2, C9.2, C10.2, C11.2, C12.2, C13.2, D1.1 (K), D5.1 (K), J1.5 (GND), J1.6 (Shield), J2.2, J3.1, J3.MP (MountPin), J4.6, J5.1, J5.11, JP1.1 (A), R5.1, R7.1, SW1.2, SW2.2, SW3.2, SW4.2, SW5.2, SW6.2, SW7.1 (A), TP1.1, U1.5 (UGND), U1.15 (GND), U1.23 (GND), U1.35 (GND), U1.43 (GND), U2.2 (VSS), U3.2 (GND)
unnamed: C1.1, U1.16 (XTAL2), X1.1
unnamed: C2.1, U1.17 (XTAL1), X1.2
unnamed: C5.1, D3.1 (K), D4.1 (K), SW7.3 (C), TP4.1, U3.1 (IN)
unnamed: C6.1, U3.4 (BP)
unnamed: C7.1, U1.42 (AREF)
unnamed: C8.1, U1.6 (UCAP)
unnamed: D1.2 (A), R3.2
unnamed: D2.1 (K), U2.1 (STAT)
unnamed: D2.2 (A), R4.2
unnamed: D5.2 (A), R12.2
unnamed: R5.2, U2.5 (PROG)
unnamed: R7.2, U1.33 (~HWB/PE2)
unnamed: SW1.1, U1.41 (PF0)
unnamed: SW2.1, U1.40 (PF1)
unnamed: SW3.1, U1.39 (PF4)
unnamed: SW4.1, U1.38 (PF5)
unnamed: SW5.1, U1.37 (PF6)
unnamed: SW6.1, U1.36 (PF7)
unnamed: TP14.1, U1.20 (PD2)
unnamed: TP15.1, U1.21 (PD3)
unnamed: TP16.1, U1.22 (PD5)
VBUS: C3.1, D3.2 (A), J1.1 (VBUS), R3.1, R4.1, TP2.1, U1.2 (UVCC), U1.7 (VBUS), U2.4 (VDD)

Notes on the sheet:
3.3v Linear Regulator
Battery Charging Indicator
ICSP
Qwiic Connector To External Controller
PWM Brightness Control
On/off Indicator
VBUS Indicator
USB Input Programming and Power
Display Module
LiPo Charger
4.5 - 5.5 V
Adafruit TFT LCD w/ Capacitive Touch
Use internal pull-ups
1 bypass cap for each VCC/AVCC pin
User Input Buttons

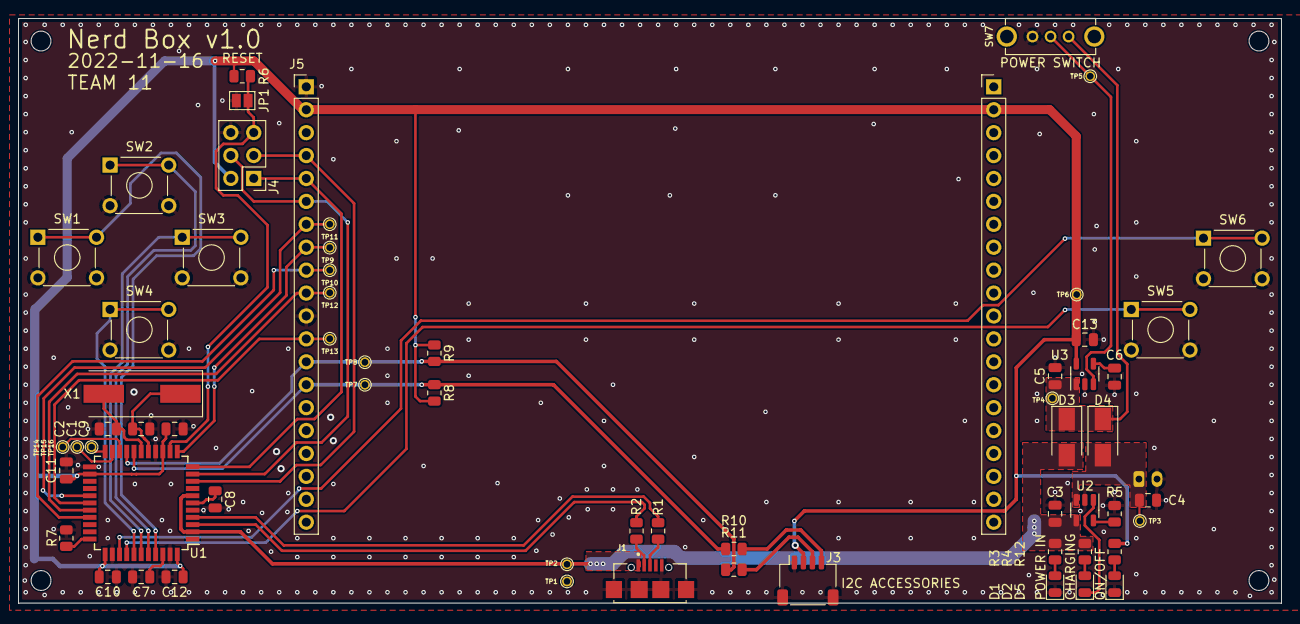
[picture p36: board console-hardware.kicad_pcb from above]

Board: 2 copper layers, 140.0 x 64.8 mm, 63 parts (1 on the bottom side), 43 nets.

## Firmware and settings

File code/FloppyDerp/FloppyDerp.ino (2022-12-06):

#include <SPI.h>

// Pin number macro definitions
#define DISPLAY_LITE 9

#define BUTTON_LEFT A5
#define BUTTON_UP A4
#define BUTTON_RIGHT A3
#define BUTTON_DOWN A2
#define BUTTON_A A1
#define BUTTON_B A0

#define BLACK    0x0000
#define BLUE     0x001F
#define RED      0xF800
#define GREEN    0x07E0
#define CYAN     0x07FF
#define MAGENTA  0xF81F
#define YELLOW   0xFFE0 
#define WHITE    0xFFFF
#define SKY      0x6DFE

// From the PDQ_GFX config file found in the library's repo
#define    ILI9341_CS_PIN               6            
#define    ILI9341_DC_PIN              11        
#define    ILI9341_RST_PIN             10            
#define    ILI9341_SAVE_SPI_SETTINGS    0

// Initialize display object

#include <PDQ_GFX.h>
#include <PDQ_ILI9341.h>
#include <Adafruit_FT6206.h>

PDQ_ILI9341 tft;
Adafruit_FT6206 ts = Adafruit_FT6206();
unsigned long int timesTouched = 0;

// Sprite bit map
const PROGMEM uint8_t ballBitMap[21 * 21] = {
    0x01, 0xfc, 0x00, 0x07, 0xff, 0x00, 0x0f, 0xff, 0x80, 0x1f, 0xff, 0xc0, 0x3f, 0xff, 0xe0, 0x7f, 
	0xff, 0xf0, 0x7f, 0xff, 0xf0, 0xf9, 0xfc, 0xf8, 0xf9, 0xfc, 0xf8, 0xff, 0xff, 0xf8, 0xff, 0xff, 
	0xf8, 0xff, 0xff, 0xf8, 0xff, 0xff, 0xf8, 0xf9, 0xfc, 0xf8, 0x78, 0xf8, 0xf0, 0x7c, 0x01, 0xf0, 
	0x3e, 0x03, 0xe0, 0x1f, 0xff, 0xc0, 0x0f, 0xff, 0x80, 0x07, 0xff, 0x00, 0x01, 0xfc, 0x00};

// Initialize global vars
int Screen=0;
int screenWidth=320;
int screenHeight=240;

// Ball vars
int ballX=screenWidth/5;
int ballY=screenHeight/4;
int ballSize = 21;
int ballColor = GREEN;
int oldY=ballY;

// Pipe vars
int pipeX = screenWidth;
int pipeY = 100;
int oldPipeY;
int pipeWidth = 40;
int pipeSpacing = 80;
int pipeSpeed = 5;

// Gravity vars
float gravity = 2;
float ballSpeedVert = 0;
int jumpHeight = 10;
float terminalSpeed = 30;

void setup() {
  Serial.begin(9600);
  delay(300);
  tft.begin();
  ts.begin();
  tft.setRotation(3);
  //canvas.setTextWrap(false);
  
  // Initialize user button inputs
  pinMode(BUTTON_LEFT, INPUT_PULLUP);
  pinMode(BUTTON_UP, INPUT_PULLUP);
  pinMode(BUTTON_RIGHT, INPUT_PULLUP);
  pinMode(BUTTON_DOWN, INPUT_PULLUP);
  pinMode(BUTTON_A, INPUT_PULLUP);
  pinMode(BUTTON_B, INPUT_PULLUP);

}

// Storing button states for debouncing
byte upPress = LOW;
byte rightPress = LOW;
byte downPress = LOW;
byte leftPress = LOW;
byte aPress = LOW;
byte bPress = LOW;
byte touchPress = LOW;

// Storing time when buttons pressed for debouncing
unsigned long upTime = 0;
unsigned long rightTime = 0;
unsigned long downTime = 0;
unsigned long leftTime = 0;
unsigned long aTime = 0;
unsigned long bTime = 0;
unsigned long touchTime = 0;

unsigned long timeSince = 0;

byte quitSelect = 0;

void loop() {
  FloppyDerp();
}

void FloppyDerp() {

/********* SETUP BLOCK *********/
  randomSeed(millis());
  drawBackground();
  initScreen();
  while (true) {
    // Display the contents of the current screen
    if(millis() - timeSince > 75){
      timeSince = millis();
      if (Screen == 0) {
        initScreen(); // Initial Screen
      }
      else if (Screen == 1) {
        gameScreen(); // Game Play Screen
      }
      else if (Screen == 2) {
        gameOverScreen(); // Game Over Screen
      }
      else if (Screen == 3) {
        pauseScreen(); // Pause Screen
      }
    }
      
    if (checkButton(digitalRead(BUTTON_A), &aPress, &aTime) || checkButton(ts.touched(), &touchPress, &touchTime)) { // Press A, play game
      if (Screen == 0) { // Initial screen
        drawBackground();
        Screen=1; // Game screen
      }
      else if (Screen == 1) { // Game screen
        jump();
      }
      else if (Screen == 3) { // Pause screen
        if (quitSelect) {
          // Return to main menu here once game is combined with UI
          drawBackground();
          Screen = 0; // For now, just restart game
        }
        else {
          drawBackground();
          Screen = 1; // Unpause game
        }
      }
    }

    if (checkButton(digitalRead(BUTTON_B), &bPress, &bTime)) { // Press B to pause
      if (Screen == 1) { // If in game screen
        tft.fillRect(screenWidth/4, screenHeight/4, screenWidth/2, screenHeight/2, BLACK); // Draw pause menu background
        quitSelect = 0;
        Screen = 3; // Pause the game
      }
      else if (Screen == 3) { // If on pause screen
        drawBackground();
        Screen = 1; // Unpause the game
      }
    }

    if (checkButton(digitalRead(BUTTON_LEFT), &leftPress, &leftTime)) {
      if (Screen == 3) { // If on pause screen
        quitSelect = 0; // Select "Don't return to main menu"
      }
    }

    if (checkButton(digitalRead(BUTTON_RIGHT), &rightPress, &rightTime)) {
      if (Screen == 3) { // If on pause screen
        quitSelect = 1; // Select "Return to main menu"
      }
    }
  }
}


/********* SCREEN CONTENTS *********/
void drawBackground() {
  tft.fillScreen(SKY);
}

void initScreen() {
  // codes of initial screen graphics
}
void gameScreen() {
  // codes of game screen
  drawBall();
  drawPipe();
  applyGravity();
  keepInScreen();
  checkCollision();
}
void gameOverScreen() {
  tft.setTextColor(WHITE);
  tft.setCursor(10, 120);
  tft.setTextSize(3);
  tft.print("You suck haha");

}

void pauseScreen() {
  tft.setCursor(94, 75);
  tft.setTextSize(2);
  tft.setTextColor(WHITE, BLACK);
  tft.print("GAME PAUSED");

  tft.setTextSize(1);
  tft.setCursor(99, 105);
  tft.print("Return to main menu?");

  if (!quitSelect) {
    tft.setTextColor(BLUE, YELLOW);
    tft.setCursor(120, 135);
    tft.print("No");
    tft.setTextColor(WHITE, BLACK);
    tft.setCursor(180, 135);
    tft.print("Yes");
  }
  else {
    tft.setTextColor(WHITE, BLACK);
    tft.setCursor(120, 135);
    tft.print("No");
    tft.setTextColor(BLUE, YELLOW);
    tft.setCursor(180, 135);
    tft.print("Yes");
  }

}

void drawBall() {
  tft.drawBitmap(ballX, ballY, ballBitMap, ballSize, ballSize, GREEN, SKY);
  clearBall();
}

void clearBall() {
  int edge = oldY;
  if ((ballY - oldY) < 0) {
    edge = ballY + ballSize;
  }

  tft.fillRect(ballX, edge, ballSize, abs(ballY - oldY), SKY);
}

void applyGravity() {
  ballSpeedVert += gravity;
  if (ballSpeedVert > terminalSpeed) {
    ballSpeedVert = terminalSpeed;
  }
  oldY = ballY;
  ballY += ballSpeedVert;
}




// keep ball in the screen

void keepInScreen() {
  // ball hits floor
  if (ballY+ballSize > screenHeight) { 
    ballY = screenHeight - ballSize;
    //ballSpeedVert = 0;
  }
  // ball hits ceiling
  if (ballY < 0) {
    ballY = 0;
    //ballSpeedVert = 0;
  }
}

void jump() {
  ballSpeedVert = -jumpHeight;
  ballY += ballSpeedVert;
  keepInScreen();
}

void drawPipe() {
  if(pipeX < 0) {
    pipeX = screenWidth;
    oldPipeY = pipeY;
    pipeY = random(20, 180);

  }

  tft.fillRect(pipeX, 0, pipeWidth, pipeY, BLACK);
  tft.fillRect(pipeX, pipeY+pipeSpacing, pipeWidth, screenHeight, BLACK);

  tft.fillRect(pipeX+pipeWidth, 0, pipeSpeed, pipeY, SKY);
  tft.fillRect(pipeX+pipeWidth, pipeY+pipeSpacing, pipeSpeed, screenHeight, SKY);

  if(pipeX > screenWidth - pipeWidth) {
    tft.fillRect((pipeX+pipeWidth-screenWidth), 0, pipeSpeed, oldPipeY, SKY);
    tft.fillRect((pipeX+pipeWidth-screenWidth), oldPipeY+pipeSpacing, pipeSpeed, screenHeight, SKY);
  }


  pipeX -= pipeSpeed;
}

void checkCollision() {
  if((pipeX < ballX+ballSize) && (pipeX+pipeWidth > ballX)) {
    if((ballY < pipeY) || (ballY+ballSize > pipeY+pipeSpacing)) {
      drawBall();
      Screen = 2;
    }
  }
}

byte checkButton(byte buttonInput, byte *buttonPress, unsigned long *buttonTime) {
  // Reads button press with debounce timer, based on debounce routine from arduino docs
  // buttonPress is the current state of the input, buttonTime is the time when the button state last changed from millis()
  // Pass pointers to variables containing button state and time

  if ((millis() - *buttonTime) > 50) {
    if (*buttonPress != buttonInput) {
      *buttonTime = millis(); // Record last time button pressed/released
      *buttonPress = buttonInput; // Change button state

      if (*buttonPress == LOW) {
        return 1; // Return true if button state was changed to low
      }   
    }
      
    return 0;
  }

  // Returns false if button state was not changed to LOW
  return 0;
}

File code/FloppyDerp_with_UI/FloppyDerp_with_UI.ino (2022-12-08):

// UI + games

// Display libraries
#include <SPI.h>

// Pin number macro definitions
#define DISPLAY_LITE 9

#define BUTTON_LEFT A5
#define BUTTON_UP A4
#define BUTTON_RIGHT A3
#define BUTTON_DOWN A2
#define BUTTON_A A1
#define BUTTON_B A0

#define BLACK    0x0000
#define BLUE     0x001F
#define RED      0xF800
#define GREEN    0x07E0
#define CYAN     0x07FF
#define MAGENTA  0xF81F
#define YELLOW   0xFFE0 
#define WHITE    0xFFFF
#define SKY      0x6DFE

// From the PDQ_GFX config file found in the library's repo
#define    ILI9341_CS_PIN               6            
#define    ILI9341_DC_PIN              11        
#define    ILI9341_RST_PIN             10            
#define    ILI9341_SAVE_SPI_SETTINGS    0

// Initialize display object
#include <PDQ_GFX.h>
#include <PDQ_ILI9341.h>
#include <Adafruit_FT6206.h>

PDQ_ILI9341 tft;
Adafruit_FT6206 ts = Adafruit_FT6206();


int gameSelect;

// Floppy derp variables
// Sprite bit map
const PROGMEM uint8_t ballBitMap[21 * 21] = {
    0x01, 0xfc, 0x00, 0x07, 0xff, 0x00, 0x0f, 0xff, 0x80, 0x1f, 0xff, 0xc0, 0x3f, 0xff, 0xe0, 0x7f, 
	0xff, 0xf0, 0x7f, 0xff, 0xf0, 0xf9, 0xfc, 0xf8, 0xf9, 0xfc, 0xf8, 0xff, 0xff, 0xf8, 0xff, 0xff, 
	0xf8, 0xff, 0xff, 0xf8, 0xff, 0xff, 0xf8, 0xf9, 0xfc, 0xf8, 0x78, 0xf8, 0xf0, 0x7c, 0x01, 0xf0, 
	0x3e, 0x03, 0xe0, 0x1f, 0xff, 0xc0, 0x0f, 0xff, 0x80, 0x07, 0xff, 0x00, 0x01, 0xfc, 0x00};

// Initialize global vars
int Screen=0;
int screenWidth=320;
int screenHeight=240;
int borderHeight = 25;
int score = 0;
byte scoreUpdated = 0;

// Ball vars
int ballX=screenWidth/5;
int ballY=screenHeight/4;
int ballSize = 21;
int ballColors[6] = {RED, YELLOW, GREEN, BLUE, MAGENTA, CYAN};
int ballSelect = 0;
int ballColor = ballColors[ballSelect+1];
int oldY=ballY;

// Pipe vars
int pipeX = screenWidth;
int pipeY = 100;
int oldPipeY;
int pipeWidth = 40;
int pipeSpacing = 80;
float pipeSpeed = 5;
float pipeIncrement = 0.1;

// Gravity vars
float gravity = 2;
float ballSpeedVert = 0;
int jumpHeight = 10;
float terminalSpeed = 30;

// Storing button states for debouncing
byte upPress = LOW;
byte rightPress = LOW;
byte downPress = LOW;
byte leftPress = LOW;
byte aPress = LOW;
byte bPress = LOW;
byte touchPress = LOW;

// Storing time when buttons pressed for debouncing
unsigned long upTime = 0;
unsigned long rightTime = 0;
unsigned long downTime = 0;
unsigned long leftTime = 0;
unsigned long aTime = 0;
unsigned long bTime = 0;
unsigned long touchTime = 0;

unsigned long timeSince = 0;

byte quitSelect = 0;
byte quitGame = 0;

// End floppy derp variables

void setup() {
  Serial.begin(9600);
  delay(300);
  tft.begin();
  ts.begin();
  tft.setRotation(3);

  // Initialize user button inputs
  pinMode(BUTTON_LEFT, INPUT_PULLUP);
  pinMode(BUTTON_UP, INPUT_PULLUP);
  pinMode(BUTTON_RIGHT, INPUT_PULLUP);
  pinMode(BUTTON_DOWN, INPUT_PULLUP);
  pinMode(BUTTON_A, INPUT_PULLUP);
  pinMode(BUTTON_B, INPUT_PULLUP);
}

void loop() {
  mainMenu();
}

void mainMenu() {
  gameSelect=1; // Reset gameSelect var
  // Print text to display for UI
  tft.setRotation(3);
  tft.fillScreen(BLACK);
  tft.setCursor(20, 20); // Cursor near top left corner
  tft.setTextColor(BLUE, YELLOW); // Blue w/ black background to show game selection
  tft.println("1. Floppy Derp                                  ");
  tft.setTextColor(RED, BLACK); // Red w/ black background
  tft.setCursor(20, 35); // Cursor on line below
  tft.println("2. {Your Game Here!}                            ");
  
  while (true) { // Button states
    if (digitalRead(BUTTON_UP) == LOW && gameSelect != 1) // User selects the game they want to play on startup. Increase the max depending on # of user-added games
    {
    gameSelect = gameSelect - 1;
    tft.setCursor(20, 20); // Cursor to Floppy Derp line on Menu
    tft.setTextColor(BLUE, YELLOW); // Highlight Floppy Derp in yellow
    tft.println("1. Floppy Derp                                  ");
    tft.setCursor(20, 35); // Cursor near top left corner
    tft.setTextColor(RED, BLACK); // Remove highlight from other menu options
    tft.println("2. {Your Game Here!}                            ");
    }
    else if (digitalRead(BUTTON_DOWN) == LOW && gameSelect != 2)
    {
    gameSelect = gameSelect + 1; // Also change the display to highlight, point to, or underline the lower number game
    tft.setCursor(20, 20); // Cursor to Floppy Derp line on Menu
    tft.setTextColor(RED, BLACK); // Highlight Floppy Derp in yellow
    tft.println("1. Floppy Derp                                  ");
    tft.setCursor(20, 35); // Cursor on line below
    tft.setTextColor(BLUE, YELLOW); // Highlight Floppy Derp in yellow
    tft.println("2. {Your Game Here!}                            ");
    }
    else if (digitalRead(BUTTON_A) == LOW) // User confirms the game they want to play
    {
      break;
    }
    }
  runGame();
}

void runGame() {
  if (gameSelect == 1) {
    FloppyDerp();
  }
  else if (gameSelect == 2) { // Play your own game!
    YourGame1();
  }
}
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

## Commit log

2022-10-20 Create .gitignore
    Ignore KiCad files
2022-10-24 Updated ball test code, and added code for detecting a shake with the imu, and making the ball jump with the imu
2022-10-24 Created KiCad schematic for hardware
    [console-hardware.kicad_pcb, console-hardware.kicad_sch]
2022-10-26 Added 3.3v regulator and LiPo charger and more
    [console-hardware.kicad_pcb, console-hardware.kicad_sch]
2022-10-27 Added buttons and display to schematic, plus some other changes
    [console-hardware.kicad_sch]
2022-11-03 Created prototype directory
2022-11-03 Updated prototype readme to include image
2022-11-03 Actually updated prototype readme for real this time
2022-11-03 Updated schematic and added preliminary layout
    [console-hardware.kicad_pcb, console-hardware.kicad_sch]
2022-11-10 Updated schematic and layout. Added BOM
    [Team 11 - BOM.xlsx, console-hardware.kicad_pcb, console-hardware.kicad_sch]
2022-11-14 Updated board layout, some small schematic fixes, and added 3D models
    [629105136821.step, B3F_1052.step, Button_Cap.step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]
2022-11-17 Updated board, fixed drc errors, added mounting holes and test points, added name
    [console-hardware.kicad_pcb, console-hardware.kicad_sch]
2022-11-17 Finishing touches to the PCB. Updated attributes for parts.
    [console-hardware.kicad_pcb, console-hardware.kicad_sch]
2022-12-02 Modified test script pin assignments, and background color/rotation
2022-12-02 Fixed pin assignments and looping bug
    [Nerd_Box_UI.ino]
2022-12-04 added STL files for enclosure
    [nerdboxEnclosure_bottom.stl, nerdboxEnclosure_top.stl]
2022-12-04 added PCB 3D render view
